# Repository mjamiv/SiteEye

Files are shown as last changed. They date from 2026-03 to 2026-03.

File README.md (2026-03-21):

# SiteEye v0.2

*AI-powered wearable for construction sites. Voice + vision in a badge-sized form factor.*

---

## What Is It

A wearable AI device built on a Raspberry Pi Zero 2W with camera, mic, speaker, and OLED display. Press a button to talk, press another to snap a photo. It sees what you see and talks back.

Designed for construction jobsites — hands-free AI that clips to your vest.

---

## Hardware

### Core
| Part | Model | Notes |
|---|---|---|
| Computer | Raspberry Pi Zero 2W | 64-bit, WiFi, BT |
| Camera | Sony IMX500 AI Camera | On-chip neural net, CSI ribbon |
| Display | Inland 1.3" OLED (SH1106) | SPI mode, IIC/SPI jumper board |
| Microphone | INMP441 I2S MEMS | Digital mic, low output (needs +25dB gain) |
| Amplifier | MAX98357A I2S DAC/Amp | 3W class D, GAIN→GND for 24dB |
| Speaker | PUI Audio AS04004PO-2-R | 4Ω 3W oval |
| Battery | PiSugar 3 + 1200mAh LiPo | Portable power |
| Buttons | Tactile push buttons (×2) | Voice + Camera triggers |

### Form Factor
- Wearable lanyard, badge-sized (~85×55×15-20mm)
- Camera forward, speaker outward, mic hole top
- OLED for glanceable status (animated eyes)

---

## Pin Map

| Pi Pin | GPIO | Device | Function |
|---|---|---|---|
| 1 | 3.3V | OLED | VCC |
| 2 | 5V | MAX98357A | VIN |
| 6 | GND | OLED | GND |
| 9 | GND | INMP441 | GND + L/R (both to GND) |
| 11 | GPIO 17 | Button 2 | Camera |
| 12 | GPIO 18 | INMP441 + MAX | SCK / BCLK (shared) |
| 13 | GPIO 27 | Button 1 | Voice |
| 14 | GND | MAX98357A | GND |
| 17 | 3.3V | INMP441 | VDD |
| 18 | GPIO 24 | OLED | DC |
| 19 | GPIO 10 | OLED | MOSI |
| 22 | GPIO 25 | OLED | RES |
| 23 | GPIO 11 | OLED | CLK |
| 24 | GPIO 8 | OLED | CS |
| 35 | GPIO 19 | INMP441 + MAX | WS / LRC (shared) |
| 38 | GPIO 20 | INMP441 | SD (data in) |
| 40 | GPIO 21 | MAX98357A | DIN (data out) |

### Reserved (future)
| Pi Pin | GPIO | Purpose |
|---|---|---|
| 8 | GPIO 14 | BLE UART TX (nRF52840) |
| 10 | GPIO 15 | BLE UART RX (nRF52840) |
| 15 | GPIO 22 | BLE RST |
| 16 | GPIO 23 | BLE INT |
| 36 | GPIO 16 | NeoPixel RGB LED |

---

## OLED Eyes

SiteEye has expressive Cozmo-style animated eyes powered by `oled_ui.py`:

### Eye Style
- **Filled white rounded rectangles** with black pupil circles and white highlight reflections
- **Lid masking** — black rectangles slide over from top/bottom for expressions
- **Asymmetric scaling** — eyes resize based on look direction (3D perspective effect)

### Expressions
| Expression | Description |
|---|---|
| Idle | Blinks, random look-around, micro-expressions (happy, curious, suspicious, confused) |
| Listening | Wide open, raised eyebrows, pulsing dots |
| Thinking | Squinted, furrowed brows, darting figure-8 eye movement |
| Speaking | Relaxed, gentle sway, mood shifts |
| Happy | Curved bottom lids (smile shape) |
| Angry | Angled top lids, furrowed brows |
| Sad | Droopy brows, angled bottom lids |
| Confused | One brow raised, one flat |
| Suspicious | One eye more squinted than the other |
| Alert | Flash-wide with exclamation mark |
| Sleepy | Slow droop to half-closed |
| Wink | Right eye only |

### Animation Features
- **Boot sequence** — eyes open from closed with quick look-around
- **Smooth pupil tracking** — lerp interpolation for natural movement
- **Saccade movements** — 30% of look changes are fast snaps (like real eyes)
- **Double blink** — 20% chance for natural feel
- **Eased transitions** — smooth in/out on all state changes
- **Eyebrows** — raised (surprise), furrowed (focus), angled (angry/sad)

---

## Software Stack

### OS
- Raspberry Pi OS Lite (64-bit, Bookworm)

### /boot/firmware/config.txt additions
```
dtparam=spi=on
dtparam=i2s=on
dtoverlay=googlevoicehat-soundcard
```

### Dependencies
```bash
sudo apt install -y python3-pip python3-pil python3-spidev sox libsox-fmt-all
pip3 install luma.oled gpiozero
```

### Audio Config

**~/.asoundrc** (and /etc/asound.conf):
```
pcm.speaker {
    type dmix
    ipc_key 1024
    slave {
        pcm "hw:1,0"
        rate 48000
        channels 2
        format S32_LE
    }
}
```

**Amp keepalive service** (eliminates click on play):
```ini
# /etc/systemd/system/amp-keepalive.service
[Unit]
Description=Keep I2S amp alive (no click)
After=sound.target
[Service]
ExecStart=/etc/systemd/system/amp-keepalive.sh
Restart=always
[Install]
WantedBy=multi-user.target
```

---

## Setup

### Quick Start
```bash
git clone https://github.com/mjamiv/SiteEye.git
cd SiteEye
scp main.py oled_ui.py setup-service.sh pi-molt@molt-device.local:~/
ssh pi-molt@molt-device.local "bash setup-service.sh"
```

### Auto-Start Service
The `setup-service.sh` script creates a systemd service that:
- Extracts API keys from `.bashrc` into `~/.env`
- Creates and enables `siteeye.service`
- Starts `main.py` automatically on boot
- Restarts on failure with 5-second delay

### Manual Control
```bash
sudo systemctl status siteeye    # check status
sudo systemctl restart siteeye   # restart
sudo systemctl stop siteeye      # stop
sudo journalctl -u siteeye -f    # live logs
```

---

## Architecture

```
┌─────────────┐     ┌──────────────┐     ┌──────────────┐
│   SiteEye   │────▶│  VPS Proxy   │────▶│  AI Backend  │
│  (Pi Zero)  │◀────│  :5757       │◀────│              │
└─────────────┘     └──────────────┘     └──────────────┘
      │                    │
      │                    ├──▶ Whisper (STT)
      ├──▶ TTS Engine      ├──▶ GPT-4o (Vision)
      ├──▶ Telegram Bot     └──▶ Sonnet (Chat)
      └──▶ OLED Display
```

### Voice Flow
1. Press Voice button → eyes go wide ("listening")
2. Record I2S mic (S32_LE, 48kHz, stereo)
3. Press again → stop recording
4. Sox boost +25dB, convert to 16kHz mono → Whisper STT
5. Eyes squint ("thinking") → Proxy `/chat` → AI response
6. Response on OLED → TTS → sox EQ → speaker
7. Eyes return to idle animation

### Camera Flow
1. Press Camera button → eyes flash alert ("capturing")
2. rpicam-still 640×480 with vflip/hflip
3. Photo sent to Telegram via bot API
4. Eyes squint ("thinking") → Proxy `/vision` → GPT-4o analysis
5. Response on OLED → TTS → speaker
6. Eyes return to idle

### Audio EQ
```
bass +6 | treble -7 3000 | lowpass 8000
```
De-esses sibilance, adds warmth. Tuned for small speaker output.

---

## Key Files

| File | Purpose |
|---|---|
| `main.py` | Device client — voice/camera flows, button handling |
| `oled_ui.py` | OLED animated eyes engine (Cozmo-style) |
| `server.py` | VPS proxy server |
| `setup-service.sh` | Auto-start service installer |

---

---

## Case Design — 3D Printed Wearable Enclosure

SiteEye ships in a custom-designed 3D printed badge-sized enclosure. Full design docs, OpenSCAD source, and STL exports are in [`case-design/`](case-design/).

### v6 Enclosure (Current)

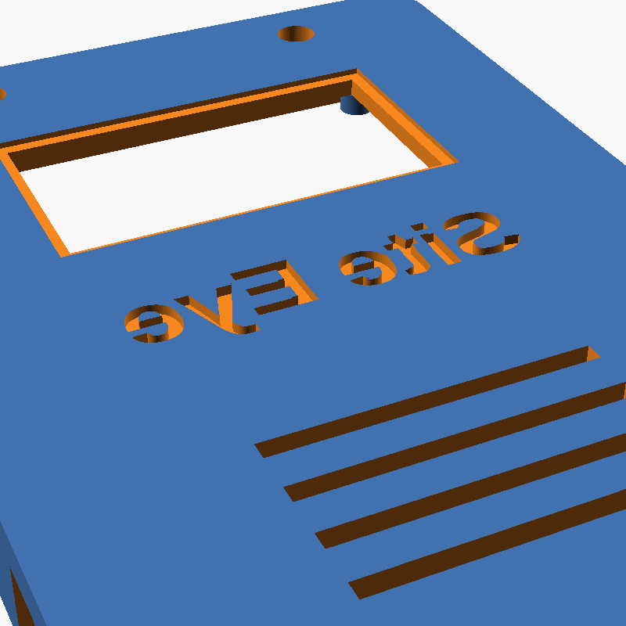
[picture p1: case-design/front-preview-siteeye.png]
SiteEye Front Shell Preview


**Form factor:** 58 × 82 × 34mm — badge-sized, lanyard-worn at chest level.

- **Two-piece snap-fit** — front shell (camera side) + back shell (OLED side), clip together at 4 corners
- **Camera faces forward** — IMX500 on the front shell, sees what you see
- **OLED faces you** — 1.3" display on the back shell, readable by glancing down
- **Single inset lanyard loop** at top — breakaway clasp for construction site safety
- **Integrated component cradles** — 36mm speaker cradle, 14mm mic cradle, Pi Zero 2W standoff pattern
- **PETG (black)** — heat/impact resistant, professional look, ~22g filament per enclosure

The v6 design addresses 13 issues from prototype review: corrected OLED mounts, dedicated mic vent, speaker cradle, bottom USB access, right-reading labels, and full interior clearance for all components including PiSugar battery.

### Build Photos

| Photo | Description |
|---|---|
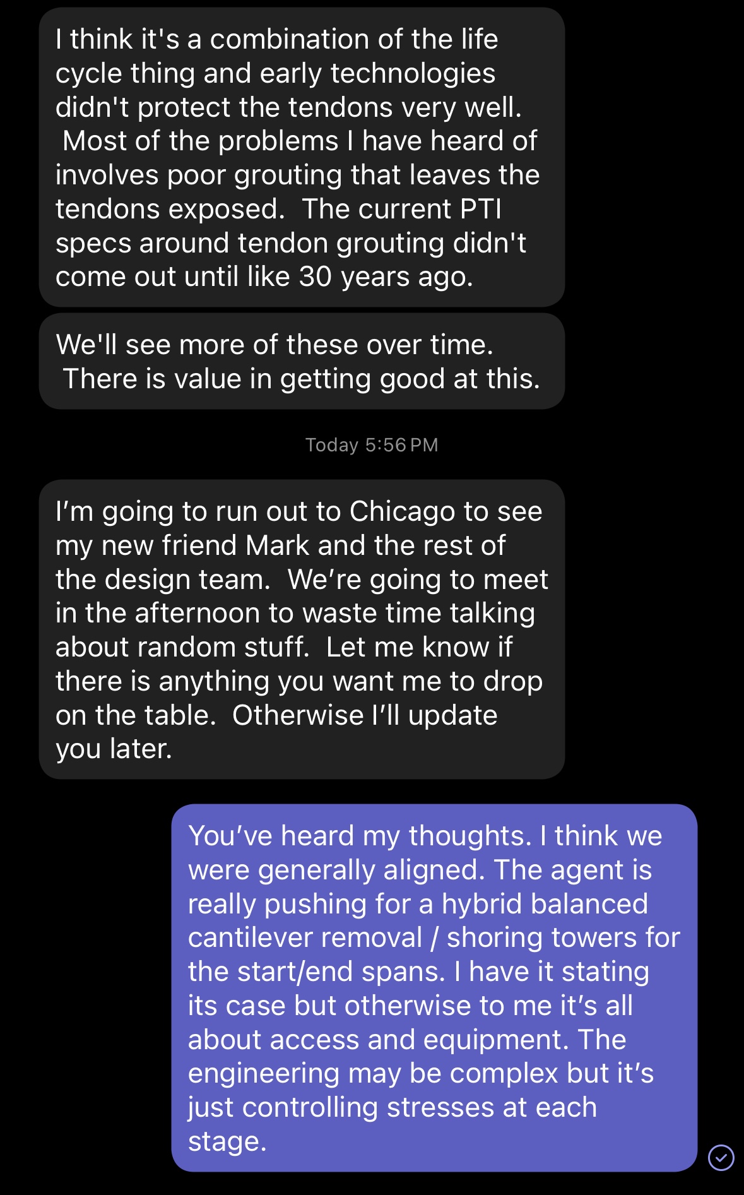
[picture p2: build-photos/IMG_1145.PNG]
|  | Assembly overview |
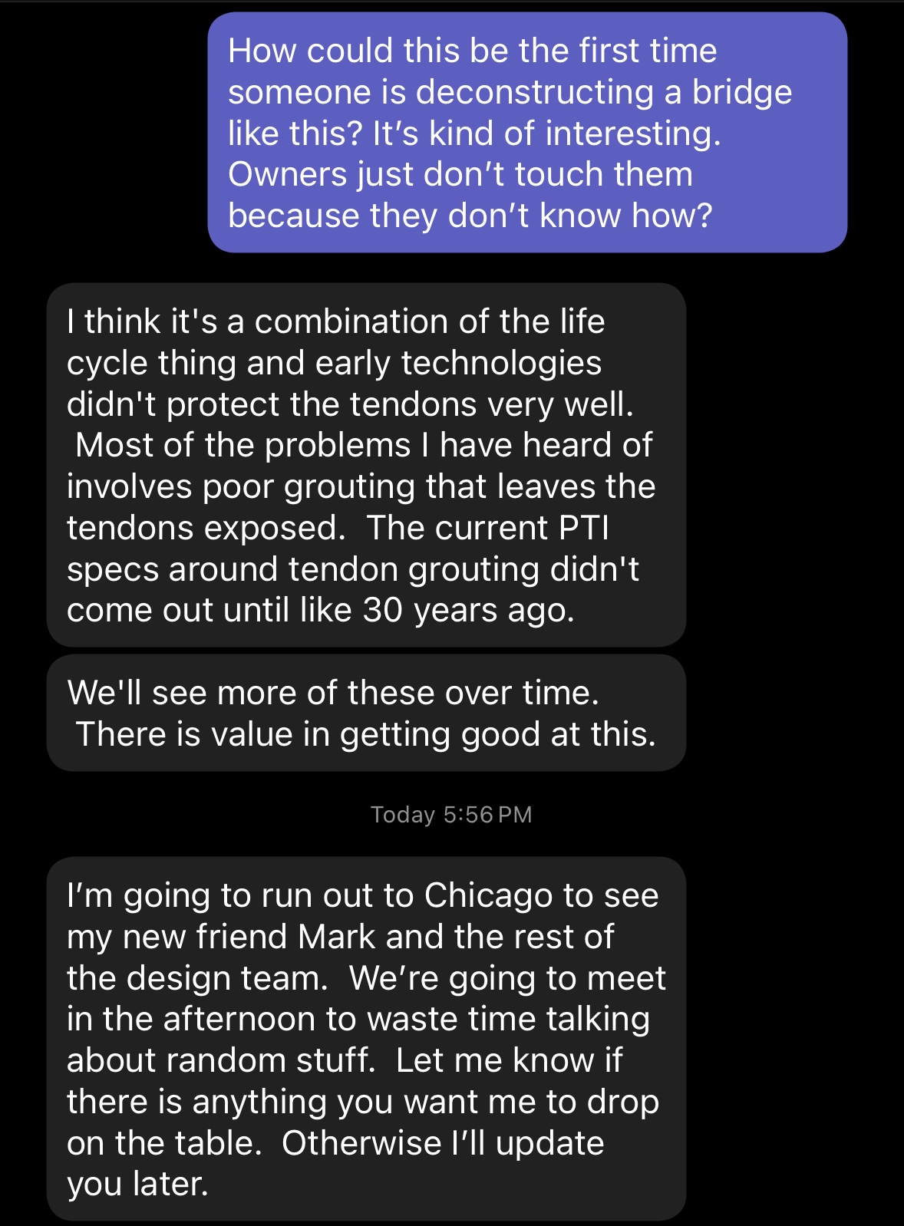
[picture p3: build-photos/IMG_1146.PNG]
|  | Front shell detail |
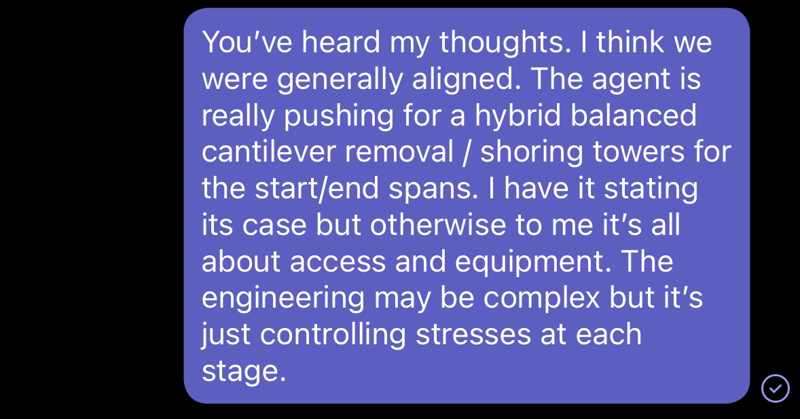
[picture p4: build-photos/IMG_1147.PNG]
|  | Internal components |
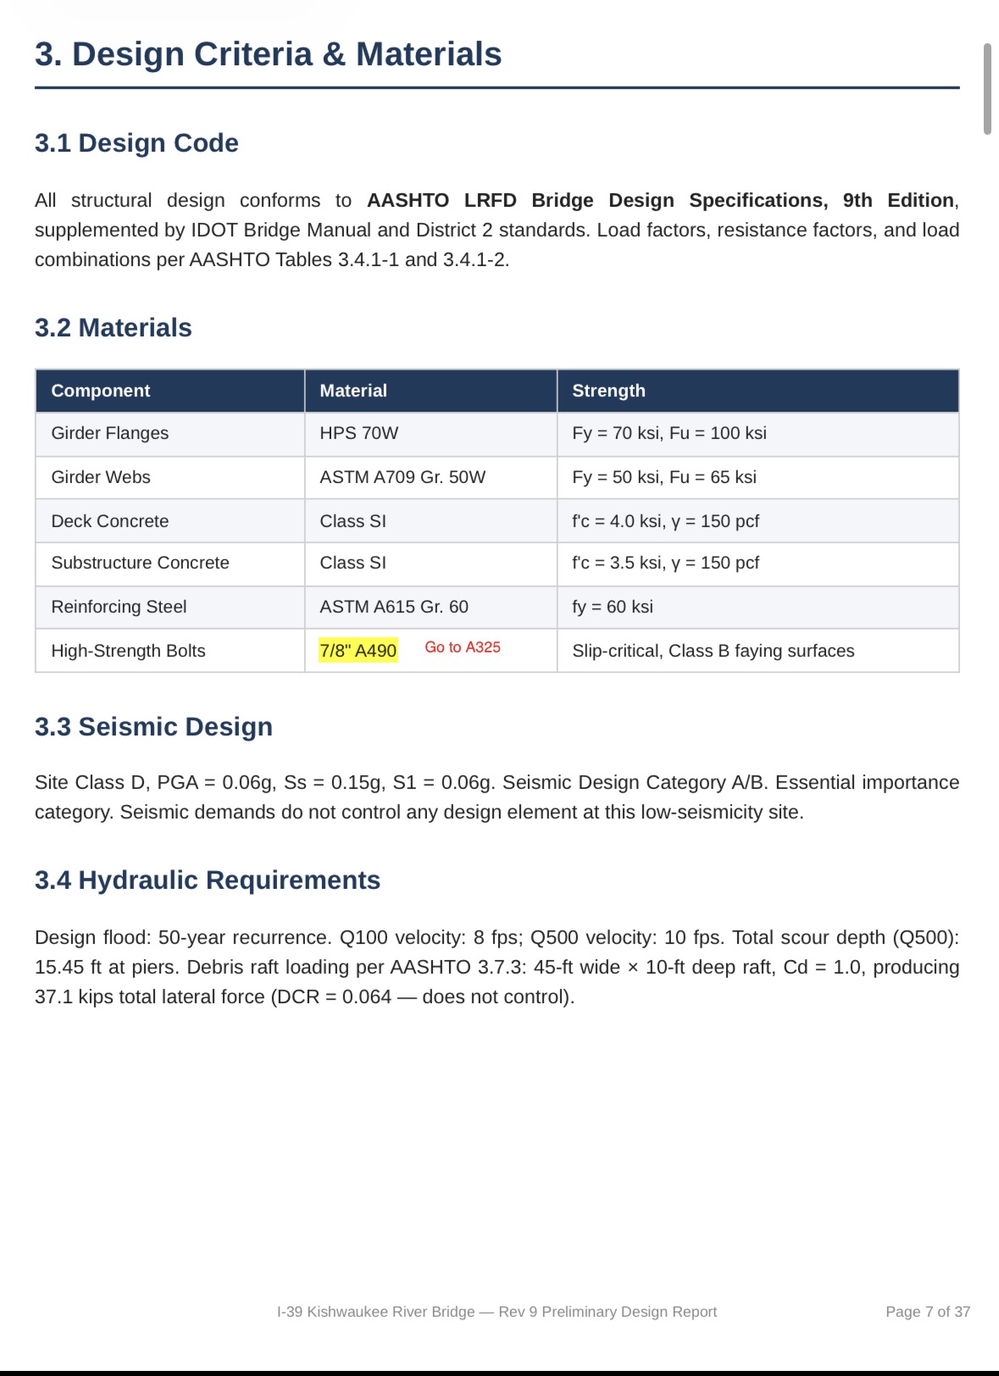
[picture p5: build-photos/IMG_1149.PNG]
|  | Camera mount |
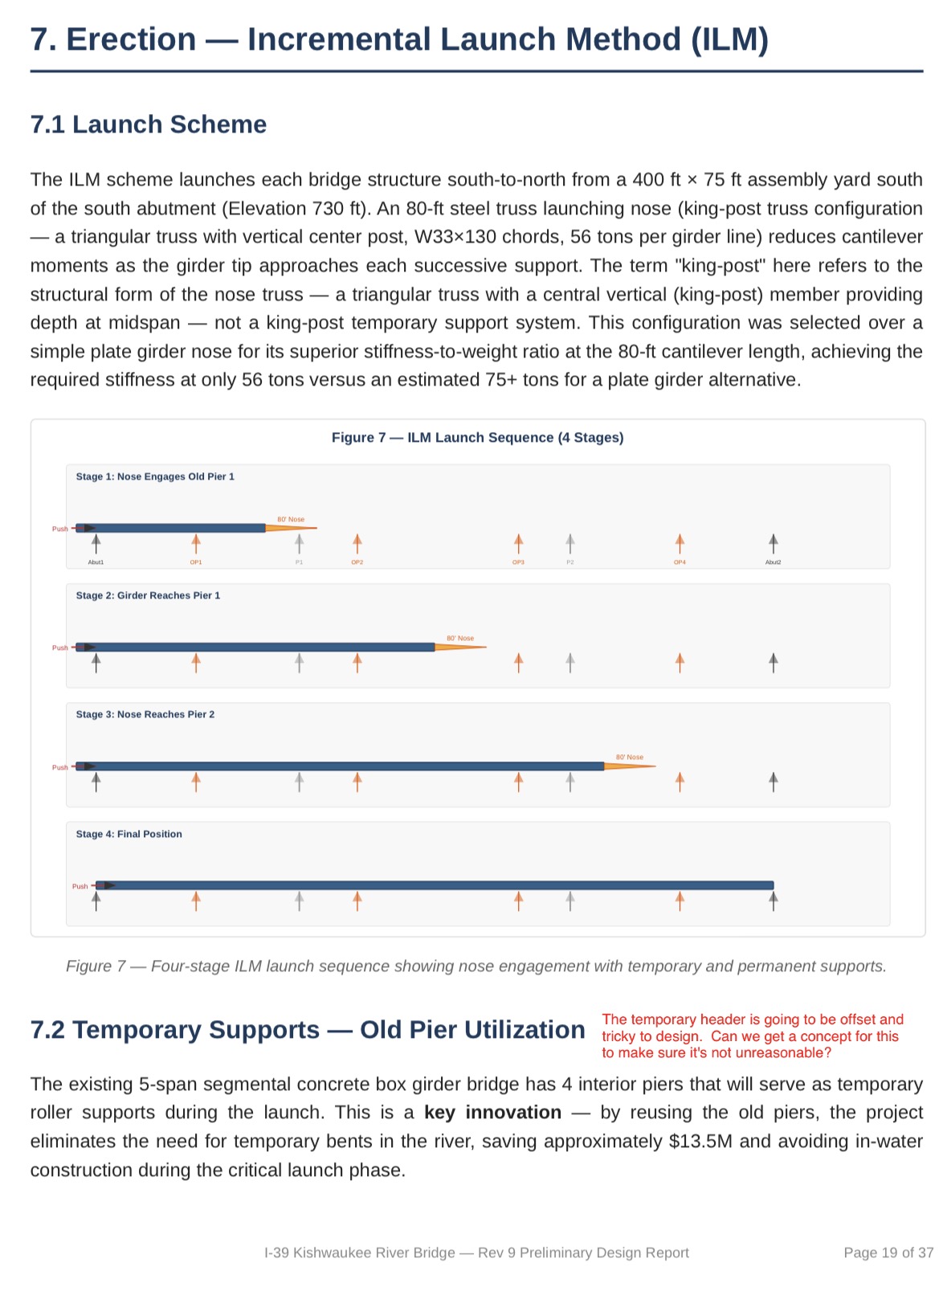
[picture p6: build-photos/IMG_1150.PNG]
|  | OLED side |
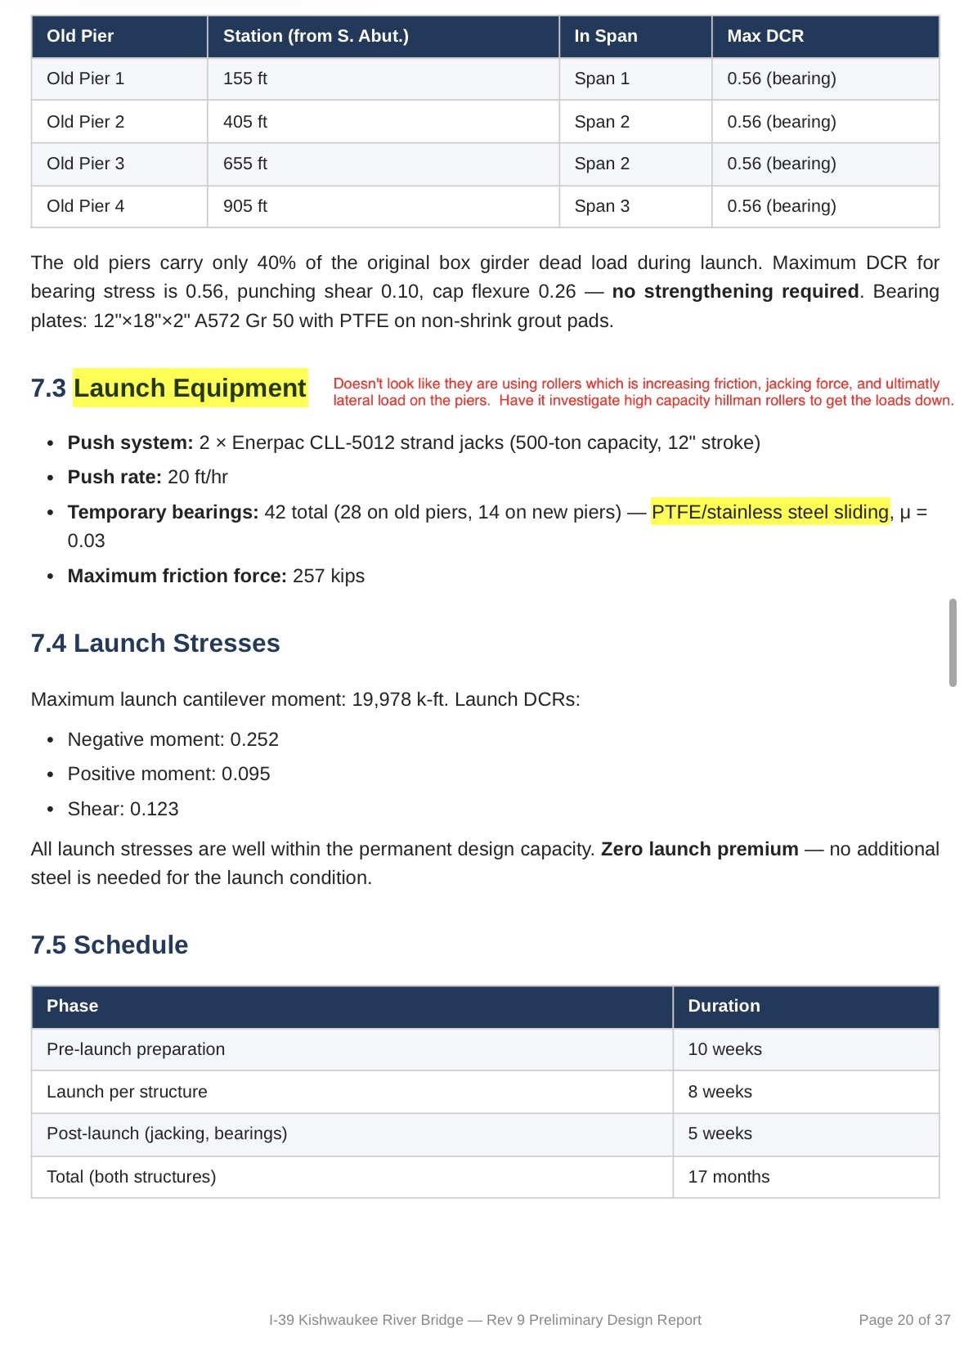
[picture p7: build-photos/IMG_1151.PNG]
|  | Assembled unit |
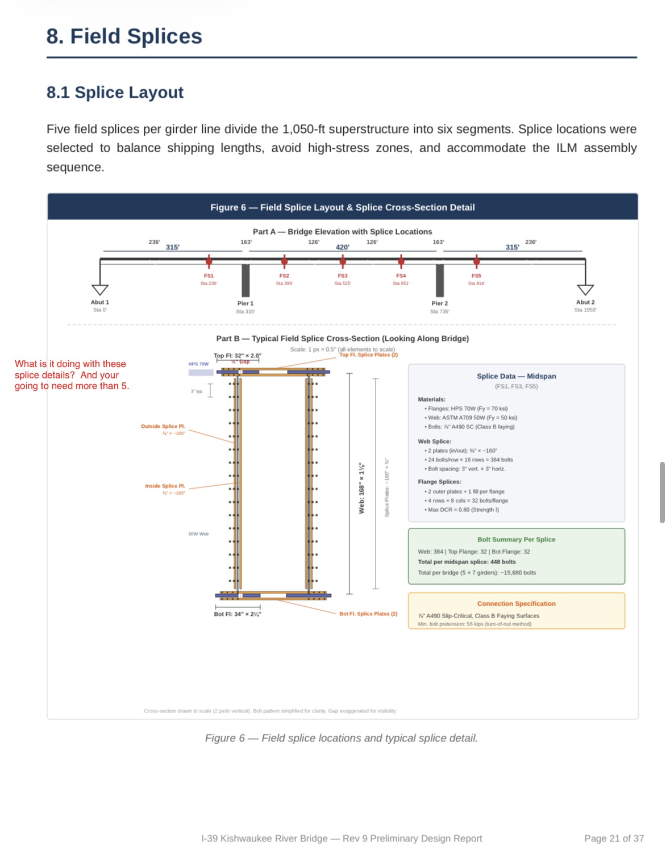
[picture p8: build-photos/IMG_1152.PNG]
|  | Worn on lanyard |
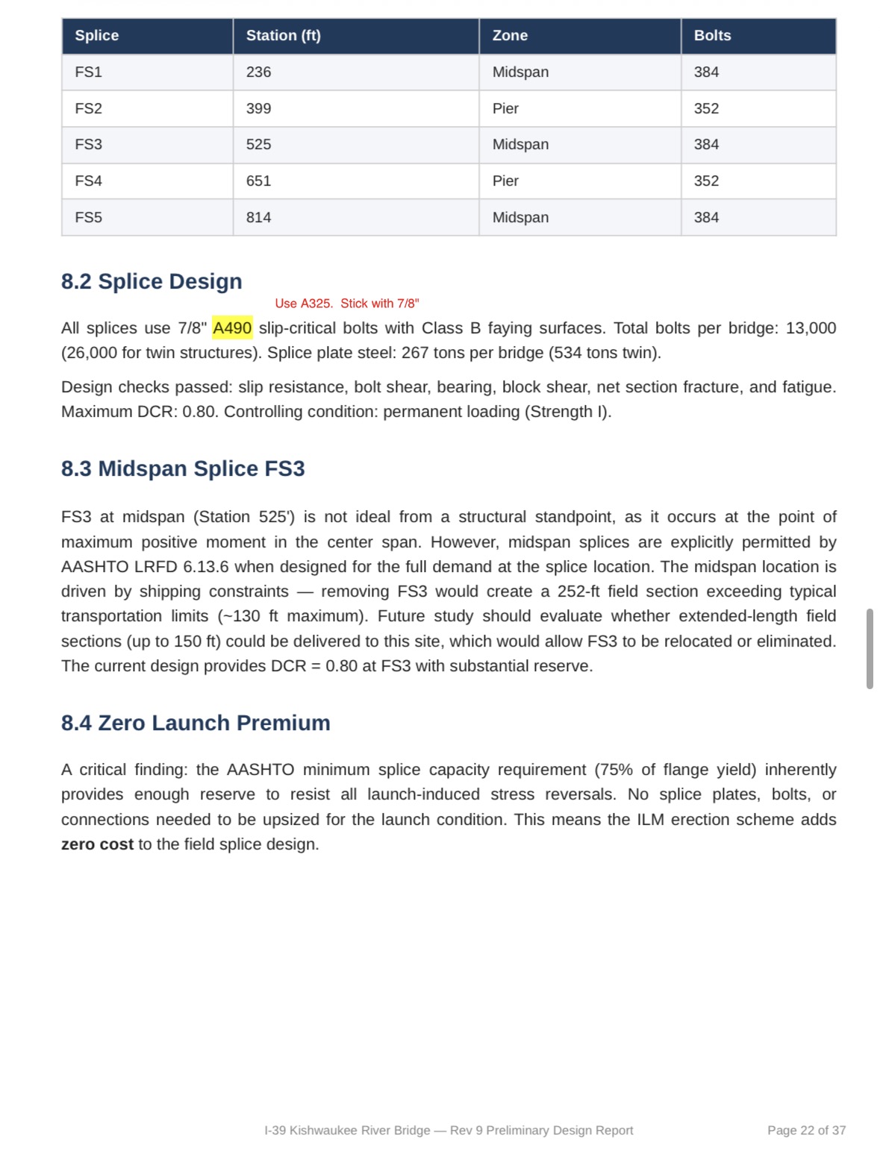
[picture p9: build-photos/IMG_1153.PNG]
|  | Side profile |

→ **[Full case design docs, STL files, and printing instructions](case-design/README.md)**

---

## Hardware Status

| Component | Status |
|---|---|
| Pi Zero 2W | ✅ Working |
| IMX500 AI Camera | ✅ Working |
| 1.3" OLED (SH1106) | ⚠️ Broken (hardware fault) |
| INMP441 Mic + MAX98357A Amp | ✅ Working |
| PUI Audio Speaker | ✅ Working |
| PiSugar 3 + 1200mAh LiPo | ✅ Working |
| Tactile Buttons (×2) | 🔲 Pending wiring |
| 3D Printed Enclosure (v6) | ✅ Designed, printing |
| NeoPixel RGB LED | 🔲 Not purchased |

---

## Known Issues & TODO
- [ ] OLED broken — replacement needed
- [ ] NeoPixel LED not purchased/wired
- [ ] Buttons pending wiring to GPIO 17/27
- [ ] OLED sometimes needs `sudo killall python3` before restart (GPIO not released)
- [ ] BLE 5.0 mesh networking (nRF52840 DNP on PCB for v1)

---

## Lessons Learned
1. **SPI speed matters on breadboard.** Default 8MHz fails — 500kHz works reliably with jumper wires.
2. **Process exit resets OLED.** luma.oled cleans up GPIO on exit — display goes blank. Keep process alive.
3. **INMP441 records low.** Always boost +20-25dB with sox before sending to STT.
4. **I2S format must match exactly.** 48kHz stereo S32_LE for both record and playback.
5. **Breadboard rows can be unreliable.** DIN wire worked direct but not through breadboard.
6. **Amp keepalive eliminates click.** dmix + silent background stream prevents power cycle pop.
7. **Buttons wire across, not along.** Same-side legs are always connected — wire to opposite legs.
8. **Kill all python3 before restarting.** GPIO won't allocate if previous process still holds pins.
9. **De-ess small speakers.** treble -7 @3kHz + lowpass 8kHz tames sibilance without killing clarity.
10. **Filled rounded rects > outlined ellipses.** Way more contrast and readability on tiny OLEDs. The Cozmo/Vector style works.
11. **Saccades make eyes feel alive.** Mix fast snaps with smooth tracking — real eyes do both.

---

## License

MIT

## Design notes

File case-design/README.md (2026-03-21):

# SiteEye Case Design — 3D Printed Wearable Enclosure

**v6 design** — Full redesign per 13-point review, March 17, 2026

---

## Form Factor

**Badge-sized wearable lanyard** — think of it as a smarter ID badge.

| Dimension | Value |
|---|---|
| Width | 58mm |
| Height | 82mm |
| Assembled Depth | 34mm (front shell 16mm + back shell 18mm) |
| Corner Radius | 4mm fillets |
| Wall Thickness | 2mm |
| Estimated Weight | ~85g assembled |

Portrait orientation, worn on a lanyard at chest level. Camera faces forward (toward what you're looking at). OLED faces you (readable by glancing down). Matches the badge convention — at home on a construction jobsite.

---

## Two-Piece Snap-Fit Design

The enclosure splits into **front shell** and **back shell**, joined by snap-fit clips at all four corners. Optional M2 screws for ruggedized/job-site use.

```
FRONT SHELL (camera side)           BACK SHELL (OLED side)
┌─────────────────────┐             ┌─────────────────────┐
│  ○  lanyard loop    │             │  ○  lanyard loop    │
│                     │             │                     │
│   ░░░░░ speaker     │             │  ┌───────────────┐  │
│   ░░░░░ vents       │             │  │  1.3" OLED    │  │
│                     │             │  │  128 × 64     │  │
│    ┌───┐  camera    │             │  └───────────────┘  │
│    │ ◉ │  lens      │             │                     │
│    └───┘            │             │  [BTN1]    [BTN2]   │
│                     │             │                     │
│  "Site Eye"         │             │                     │
│  "Prototype v1"     │             │                     │
│                     │             │                     │
│   ◎  mic vent       │             │                     │
│                     │             │                     │
└────────┬────────────┘             └─────────────────────┘
         │
    micro-USB (bottom)
```

**Print orientation:** Each shell face-down (outer face on build plate). Best surface finish on the visible face, snap-fit clips print vertically for maximum strength.

---

## Component Mounting

| Component | Location | Mounting Method |
|---|---|---|
| Pi Zero 2W | Back shell interior | M2.5 standoffs, 23×58mm c-c pattern |
| IMX500 AI Camera | Front shell (forward-facing) | Camera cradle, 8mm lens opening with bezel |
| 1.3" OLED (SH1106) | Back shell (user-facing) | 4-post mount, 30mm c-c, 3mm screw holes |
| Speaker (4Ω 3W oval) | Front shell | 36mm speaker cradle behind vent slots |
| MEMS Microphone (INMP441) | Front shell top | 14mm mic cradle behind vent hole |
| PiSugar 3 LiPo battery | Back shell, between Pi and back wall | Snap-in, accessible from bottom |
| Tactile buttons (×2) | Back shell, below OLED | Cutouts for right-thumb access |

**CSI ribbon cable** routes through internal channel from camera (front) to Pi (back), with 180° fold.

---

## v6 Design — 13-Point Redesign

Version 6 is a full redesign addressing 13 issues from prototype review (March 17, 2026):

1. **Labels mirrored** — correct exterior reading (right-reading when printed face-down)
2. **Labels on camera (front) side** — smaller font, cleaner look
3. **Camera moved down ~19mm** — better FOV from chest-level position
4. **OLED mounts corrected** — 30mm c-c, 3mm holes, 35.5×33.5mm module, 34×18.5mm screen window
5. **Assembled depth 34mm** — 16mm front + 18mm back = 30mm+ internal clearance for all components
6. **Front mic opening added** — dedicated vent hole for INMP441 microphone
7. **Side micro-USB slot** — 10mm deep × 20mm wide, 15mm from top, for power access
8. **Bottom opening** — single centered hole for micro-USB access (cleaner than per-shell holes)
9. **36mm speaker cradle** — behind front vent slots, sized for PUI Audio AS04004PO-2-R
10. **14mm mic cradle** — behind front mic opening, holds INMP441 in position
11. **Single inset lanyard loop** — at top center (replaces dual lanyard holes, stronger)
12. **Pi Zero 2W screw holes** — 23×58mm c-c, centered on back plate
13. **Tactile button cutouts** — on back shell below OLED (replaced removed back vents)

---

## Files

### OpenSCAD Source
| File | Description |
|---|---|
| `molt-case.scad` | Main parametric model (v6, all components) |
| `export-front.scad` | Front shell export (with text labels) |
| `export-front-notext.scad` | Front shell export (no text, cleaner) |
| `export-back.scad` | Back shell export |
| `render-preview.scad` | Assembled preview render |

### STL Exports
| File | Description |
|---|---|
| `molt-case-front-v6.stl` | **Current** — front shell with labels |
| `molt-case-front-v6-notext.stl` | **Current** — front shell, no text |
| `molt-case-back-v6.stl` | **Current** — back shell |
| `molt-case-front-v5.stl` | v5 front (reference) |
| `molt-case-front-v4-siteeye.stl` | v4 front with SiteEye branding |
| `molt-case-back-v4.stl` | v4 back (reference) |

### Visualization
| File | Description |
|---|---|
| `front-preview-siteeye.png` | Rendered preview of front shell |

---

## Printing Instructions

### Recommended Settings

| Parameter | Value |
|---|---|
| **Material** | PETG (black) — preferred for heat/impact resistance |
| **Alternative** | PLA — faster iteration during development |
| **Layer Height** | 0.2mm |
| **Wall Perimeters** | 3 (strength for snap-fits) |
| **Infill** | 15-20% gyroid or honeycomb |
| **Print Temperature** | 230°C (PETG) / 215°C (PLA) |
| **Bed Temperature** | 70°C (PETG) / 60°C (PLA) |
| **Supports** | Minimal — button cutouts may need minimal support |
| **Orientation** | Face-down on bed (outer surface = best finish) |

### Time & Material
- Front shell: ~2.5 hrs, ~12g
- Back shell: ~2 hrs, ~10g
- Total filament: ~22g per enclosure (~$1.10 in PETG)

---

## Assembly Guide

### Tools Needed
- M2.5 × 6mm standoffs (4×)
- M2.5 × 4mm screws (8×)
- M2 × 6mm screws (2×, optional — for snap-fit reinforcement)
- Tweezers for ribbon cable routing
- Thin double-sided tape for wire management

### Step-by-Step

1. **Install Pi standoffs** — Thread 4× M2.5 standoffs into back shell mounting holes (23×58mm pattern, centered)

2. **Mount Pi Zero 2W** — Seat on standoffs, screw with M2.5 × 4mm screws. Leave GPIO header accessible.

3. **Route CSI ribbon** — Thread camera ribbon cable through the internal channel. Leave slack for 180° fold.

4. **Install OLED** — Seat into 4-post mount on back shell. Ribbon or wire down to Pi GPIO (SPI: pins 8, 10, 11, 24, 25).

5. **Install buttons** — Press tactile switches into button cutouts on back shell. Wire to Pi GPIO 17 (camera) and GPIO 27 (voice).

6. **Install microphone** — Seat INMP441 into 14mm mic cradle behind front shell mic vent. Route wires through interior.

7. **Install speaker** — Seat speaker into 36mm front-shell cradle behind vent slots. Connect to MAX98357A amp.

8. **Attach PiSugar battery** — Connect to Pi Zero 2W (attaches underneath Pi). Add last — interferes with debugging.

9. **Connect camera** — Attach IMX500 AI Camera to Pi CSI port via ribbon. Seat camera in front-shell lens pocket.

10. **Snap shells together** — Align front and back shell, press at all four corners until clips engage.

11. **Thread lanyard** — Route through top inset loop, attach breakaway clasp.

> ⚠️ **Add PiSugar last.** The battery module physically blocks GPIO access once installed.

---

## Version History

| Version | Date | Key Changes |
|---|---|---|
| v1/v2 | Feb 2026 | Initial concept — badge form factor proof |
| v3 | Mar 2026 | First printable model |
| v4 | Mar 2026 | SiteEye branding, camera bezel |
| v5 | Mar 2026 | OLED mount fixes, button placement |
| **v6** | **Mar 17, 2026** | **13-point redesign — current version** |

---

## Design Rationale

| Decision | Choice | Why |
|---|---|-----|
| Orientation | Portrait (vertical) | Matches badge convention, natural chest hang |
| Camera side | Front shell (forward-facing) | Captures user's perspective |
| OLED side | Back shell (user-facing) | Readable by glancing down |
| Buttons | Back shell, below OLED | Right-thumb access while hanging |
| Assembly | Snap-fit + optional screws | Fast iteration + job-site durability |
| Material | PETG (black) | Heat/impact resistant, professional look |
| Cooling | Passive vents only | Pi Zero 2W thermals manageable without fan |
| Lanyard | Single loop (breakaway) | Safety-critical for construction sites |
| Depth | 34mm assembled | Accommodates all components including PiSugar |
| Labels | Camera (front) side only | Clean OLED side, branded front |

---

*Designed by Molt AI for Michael Martello. Living document — updates with each revision.*

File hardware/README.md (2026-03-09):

# SiteEye Hardware — PCB Design

## Overview

Custom PCB to replace breadboard wiring. Eliminates signal integrity issues (SPI speed, I2S timing) and fits the badge-sized wearable form factor.

## Design Goals

1. **Badge form factor:** ~85×55mm, 2-layer PCB
2. **Pi Zero 2W** mounts via 2×20 GPIO header (removable) or castellated pads (permanent)
3. **All peripherals on-board:** OLED, mic, amp, buttons, speaker connector
4. **BLE 5.0 mesh-ready:** Unpopulated footprint for nRF52840 or ESP32-C3 module (future multi-device mesh networking for jobsites without cell service)
5. **PiSugar compatible:** Clearance underneath for PiSugar 3 battery board
6. **Camera:** CSI ribbon passthrough (not on PCB)

## Components

| Ref | Component | Package | Notes |
|-----|---|---|---|
| U1 | Raspberry Pi Zero 2W | 2×20 header | Host computer |
| U2 | INMP441 | Breakout board | I2S MEMS microphone |
| U3 | MAX98357A | Breakout board | I2S DAC/amplifier |
| U4 | SH1106 1.3" OLED | SPI breakout | Display |
| U5 | nRF52840 module | Castellated (future) | BLE 5.0 mesh radio — DNP v1 |
| SW1 | Tactile button | 6mm 4-pin | Voice trigger |
| SW2 | Tactile button | 6mm 4-pin | Camera trigger |
| LED1 | NeoPixel WS2812B | 5050 SMD | Status RGB LED |
| SP1 | PUI AS04004PO-2-R | Wire pads | 4Ω 3W speaker |
| J1 | CSI ribbon connector | 22-pin FPC | Camera passthrough |
| J2 | JST-PH 2-pin | Through-hole | Speaker connector |
| J3 | 2×20 GPIO header | 2.54mm pitch | Pi Zero mount |

## Net List

### Power Rails
| Net | Source | Destinations |
|-----|---|---|
| 3V3 | Pi Pin 1 | OLED VCC, INMP441 VDD |
| 5V | Pi Pin 2 | MAX98357A VIN |
| GND | Pi Pin 6,9,14 | All components |

### I2S Audio Bus (shared)
| Net | Pi GPIO | Pin | Destinations |
|-----|---|-----|---|
| I2S_BCLK | GPIO 18 | 12 | INMP441 SCK, MAX98357A BCLK |
| I2S_LRCLK | GPIO 19 | 35 | INMP441 WS, MAX98357A LRC |
| I2S_DIN | GPIO 20 | 38 | INMP441 SD (mic data) |
| I2S_DOUT | GPIO 21 | 40 | MAX98357A DIN (speaker data) |

### SPI Display
| Net | Pi GPIO | Pin | Destination |
|-----|---|-----|---|
| SPI_MOSI | GPIO 10 | 19 | OLED MOSI |
| SPI_CLK | GPIO 11 | 23 | OLED CLK |
| SPI_CS | GPIO 8 | 24 | OLED CS |
| OLED_DC | GPIO 24 | 18 | OLED DC |
| OLED_RST | GPIO 25 | 22 | OLED RES |

### GPIO
| Net | Pi GPIO | Pin | Destination |
|-----|---|-----|---|
| BTN_VOICE | GPIO 27 | 13 | SW1 (pull-up, active low) |
| BTN_CAMERA | GPIO 17 | 11 | SW2 (pull-up, active low) |
| NEOPIXEL | GPIO 16 | 36 | LED1 data in |

### INMP441 Config
| Pin | Connection |
|-----|---|
| L/R | GND (left channel select) |

### MAX98357A Config
| Pin | Connection |
|-----|---|
| GAIN | GND (24dB fixed gain) |
| SD | NC or pull-up (always on) |

### BLE Mesh Module (future, v2+)
| Net | Pi GPIO | Module Pin | Notes |
|-----|---|---|---|
| UART_TX | GPIO 14 | RXD | Serial command interface |
| UART_RX | GPIO 15 | TXD | Serial command interface |
| BLE_RST | GPIO 22 | RESET | Module reset |
| BLE_INT | GPIO 23 | IRQ | Interrupt line |
| 3V3 | — | VCC | Shared 3.3V rail |
| GND | — | GND | — |

## PCB Layout Notes

### Layer Stack
- **Top:** Components, signal traces
- **Bottom:** Ground plane, PiSugar clearance

### Placement
```
┌──────────────────────────────┐
│  [OLED]          [CAM ribbon]│
│                              │
│  [MIC]    [nRF52840 future]  │
│                              │
│  [SW1]  [SW2]  [NeoPixel]   │
│                              │
│  ════════════════════════════│ ← Pi Zero GPIO header
│  [MAX98357A]    [Speaker J2] │
└──────────────────────────────┘
        (bottom: PiSugar)
```

### Design Rules
- Trace width: 0.25mm signal, 0.5mm power
- Clearance: 0.2mm minimum
- Via size: 0.3mm drill, 0.6mm pad
- I2S traces: matched length, keep short
- SPI traces: keep under 50mm, ground guard
- Decoupling caps: 100nF on each VCC pin

## BOM (v1 — no mesh radio)

| Qty | Part | Est. Cost |
|-----|---|---|
| 1 | Custom PCB (5 pcs) | $5-15 |
| 1 | 2×20 female header | $1 |
| 2 | 6mm tactile button | $0.50 |
| 1 | WS2812B NeoPixel | $0.30 |
| 1 | JST-PH 2-pin connector | $0.20 |
| 4 | 100nF 0805 caps | $0.10 |
| — | **Total per board** | **~$7-17** |

(Breakout boards for INMP441, MAX98357A, OLED, Pi Zero purchased separately)

## Fabrication

Recommended fabs:
- **JLCPCB** — cheapest, 5 boards ~$5, PCBA available
- **PCBWay** — good quality, slightly more
- **OSH Park** — US-based, purple boards, ~$15 for 3

## Future: Bluetooth Mesh (v2+)

The nRF52840 footprint enables BLE 5.0 Mesh networking for multi-device jobsite communication without cell service. Architecture:

```
[SiteEye A] ←BLE Mesh→ [SiteEye B] ←BLE Mesh→ [SiteEye C]
     ↑                       ↑                       ↑
  Worker 1              Worker 2              Worker 3
                             ↓
                    [Gateway Node]
                         ↓
                   [Cloud/Server]
```

- Mesh relay: each device acts as a node, forwarding messages
- Range: ~100m outdoor per hop, multi-hop extends coverage
- Use cases: safety alerts, task coordination, voice relay, location tracking
- Protocol: Bluetooth Mesh (IEEE 802.15.1) or custom on BLE 5.0 advertising

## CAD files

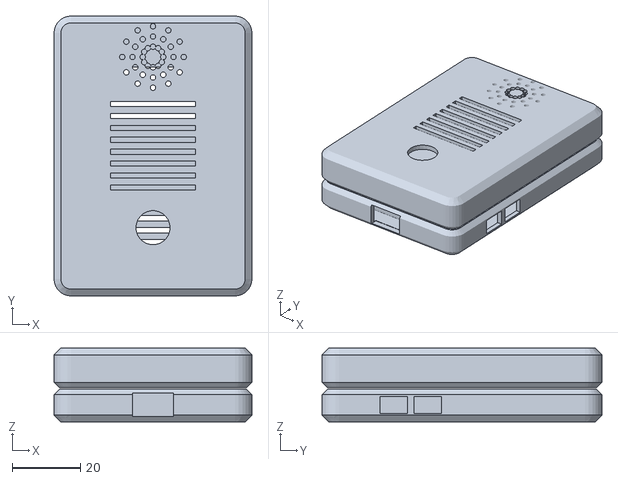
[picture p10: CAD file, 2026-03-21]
case-design/molt-device-assembled.stl
58.0 x 82.0 x 21.6

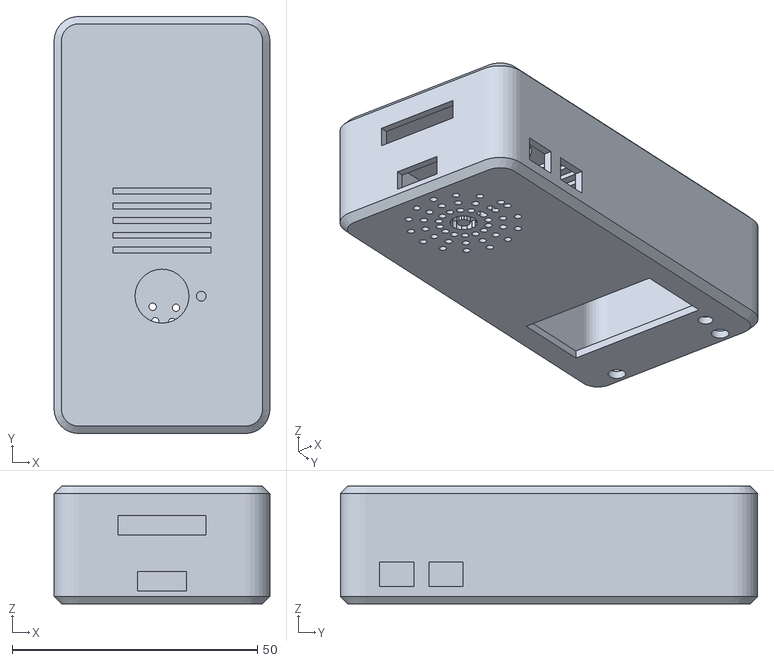
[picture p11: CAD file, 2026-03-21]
case-design/molt-v2-assembled.stl
44.0 x 85.0 x 24.0

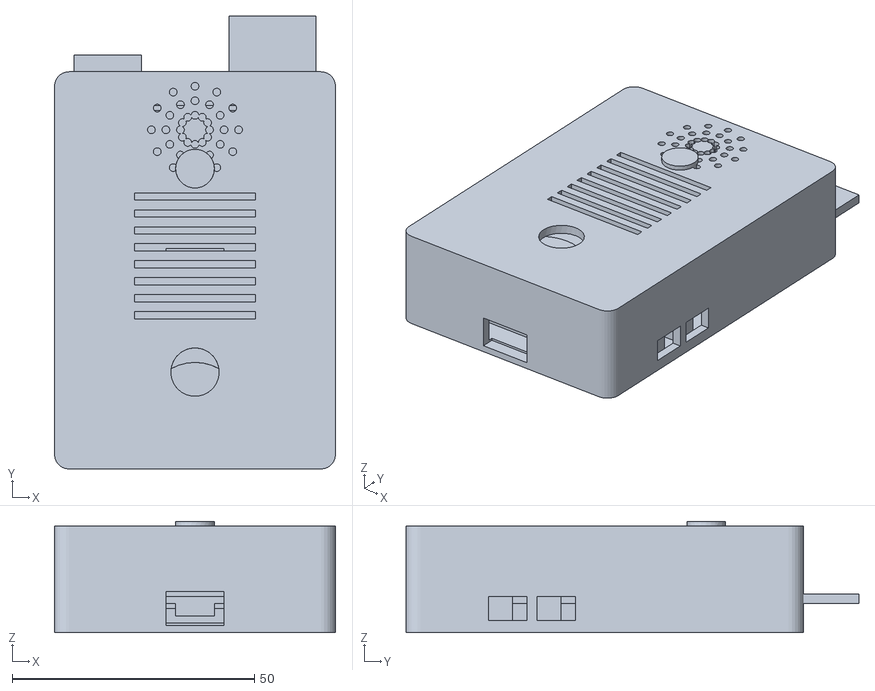
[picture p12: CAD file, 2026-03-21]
case-design/molt-device-full-model.stl
58.0 x 93.5 x 23.0

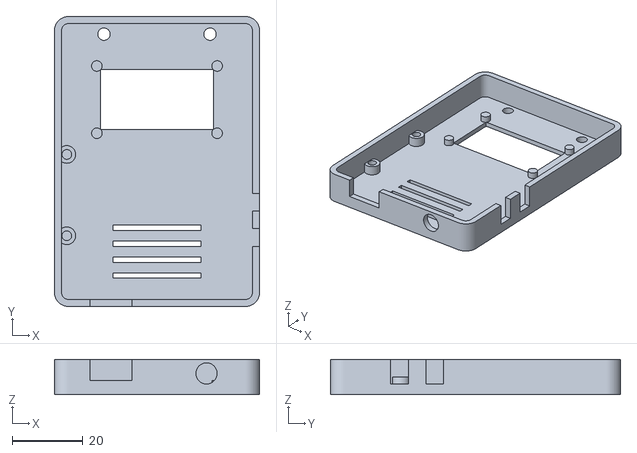
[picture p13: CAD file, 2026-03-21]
case-design/molt-case-front-v4-siteeye.stl
58.0 x 82.0 x 10.0

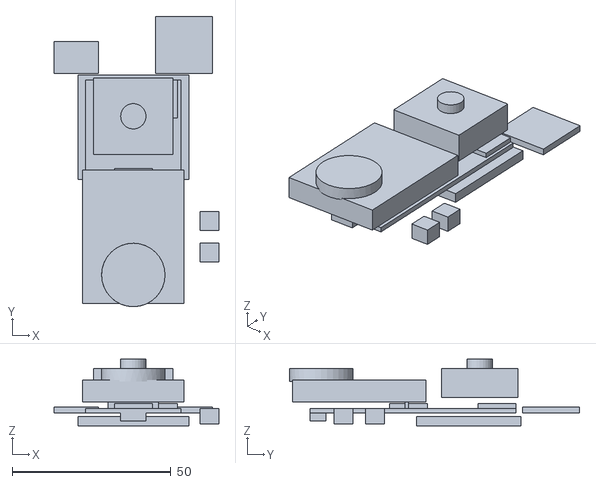
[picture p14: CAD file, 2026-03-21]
case-design/molt-device-components.stl
52.0 x 91.5 x 21.0

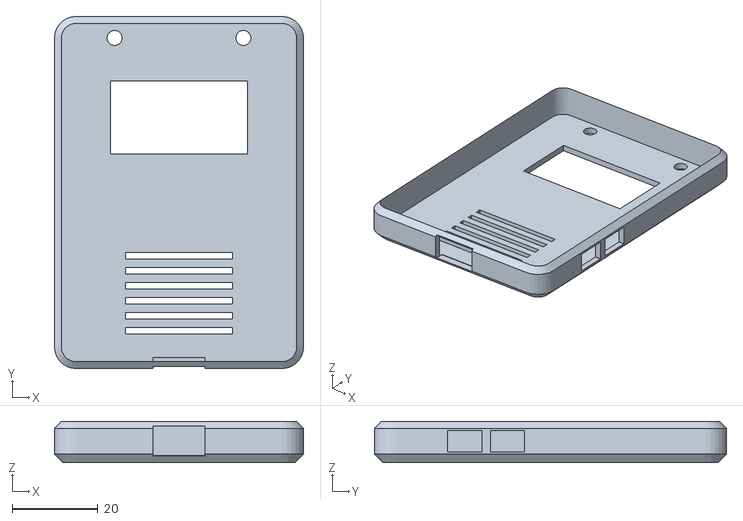
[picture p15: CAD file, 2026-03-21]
case-design/molt-device-front.stl
58.0 x 82.0 x 9.60

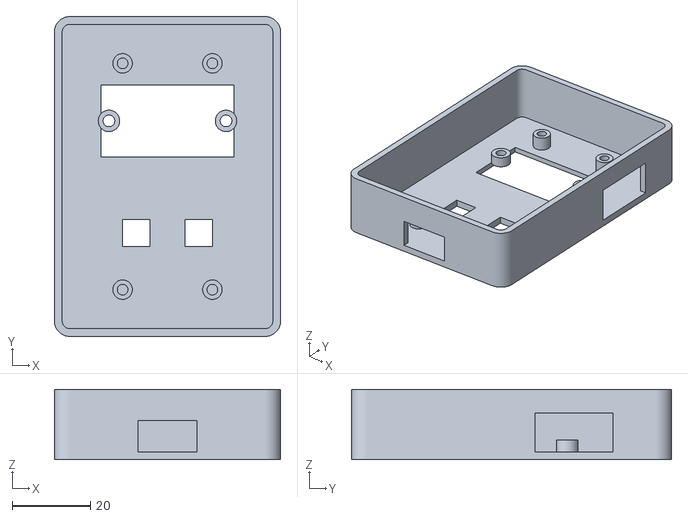
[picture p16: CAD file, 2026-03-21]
case-design/molt-case-back-v6.stl
58.0 x 82.0 x 18.0

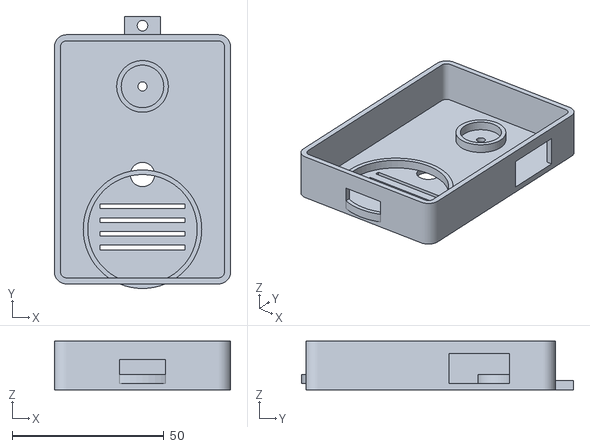
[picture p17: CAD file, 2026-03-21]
case-design/molt-case-front-v6.stl
58.0 x 89.5 x 16.0

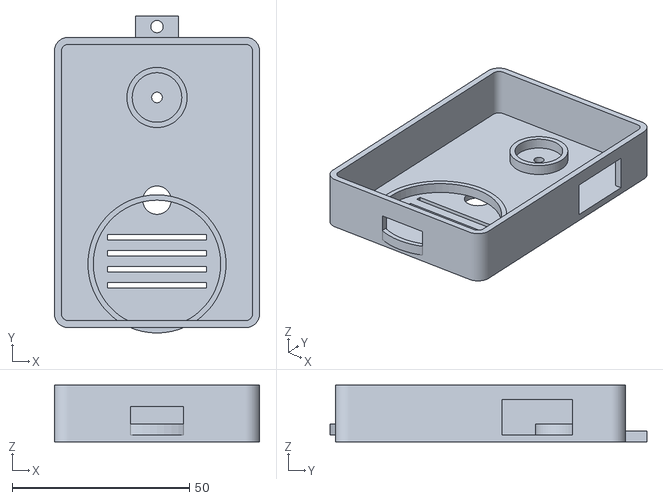
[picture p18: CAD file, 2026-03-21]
case-design/molt-case-front-v6-notext.stl
58.0 x 89.5 x 16.0

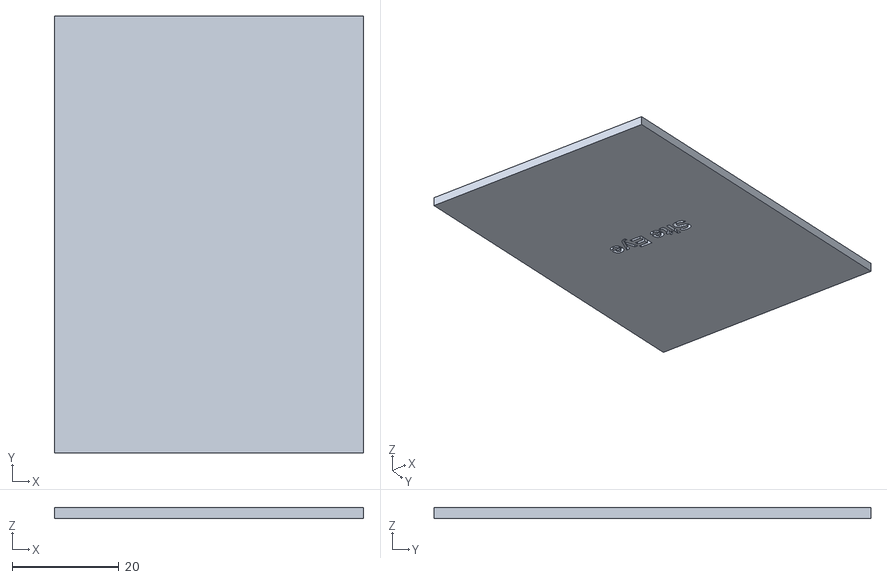
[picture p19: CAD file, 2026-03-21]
case-design/test-text.stl
58.0 x 82.0 x 2.00

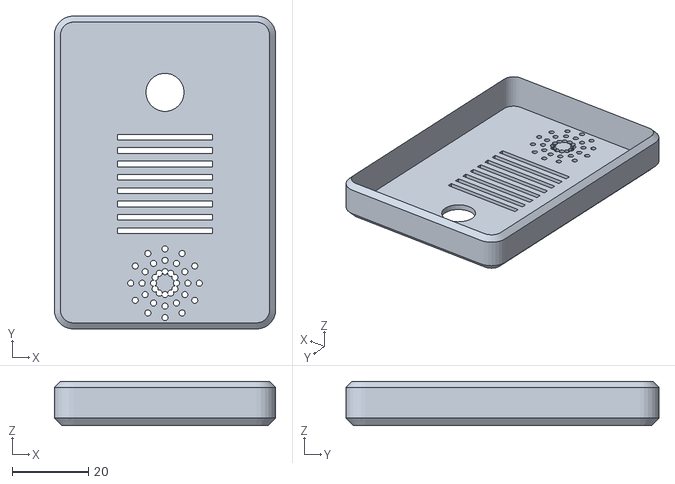
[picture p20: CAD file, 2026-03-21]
case-design/molt-device-back.stl
58.0 x 82.0 x 11.6

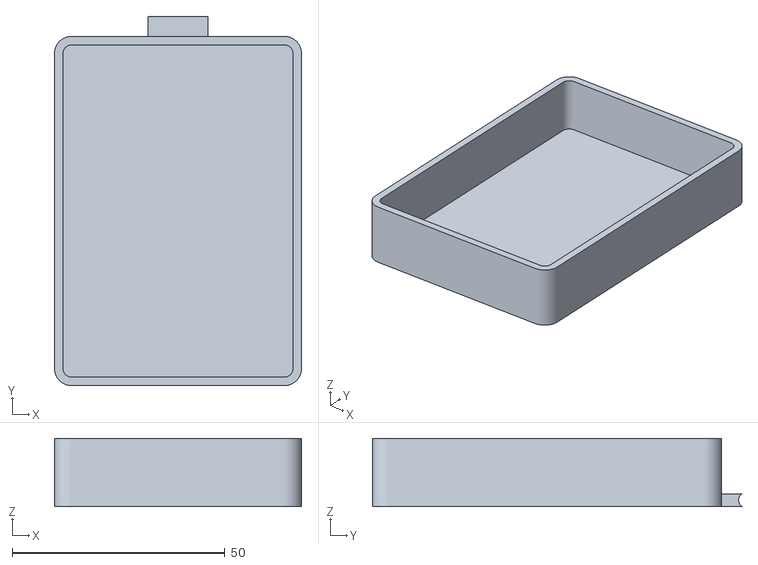
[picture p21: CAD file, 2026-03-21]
case-design/test-notext.stl
58.0 x 86.7 x 16.0

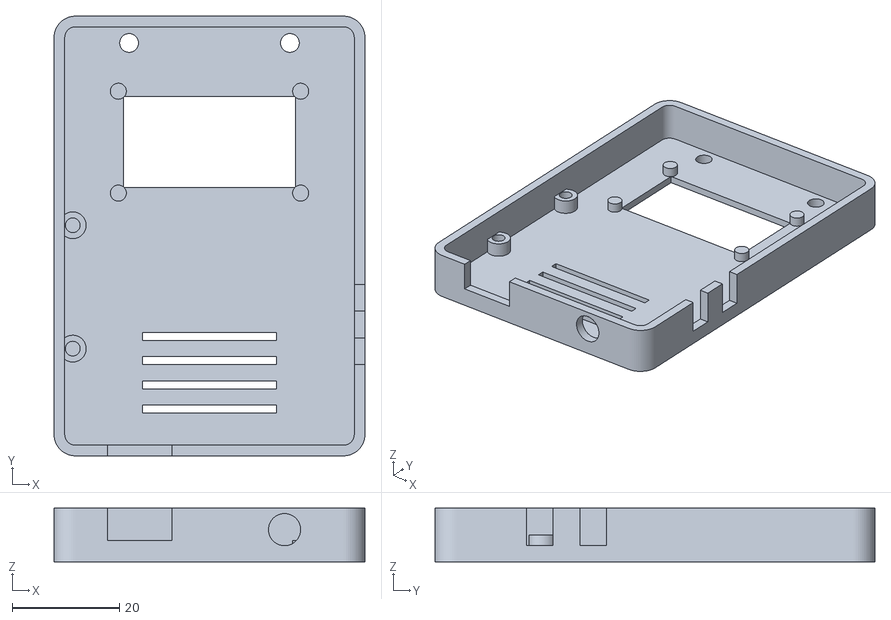
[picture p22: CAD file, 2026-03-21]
case-design/molt-v3-front.stl
58.0 x 82.0 x 10.0

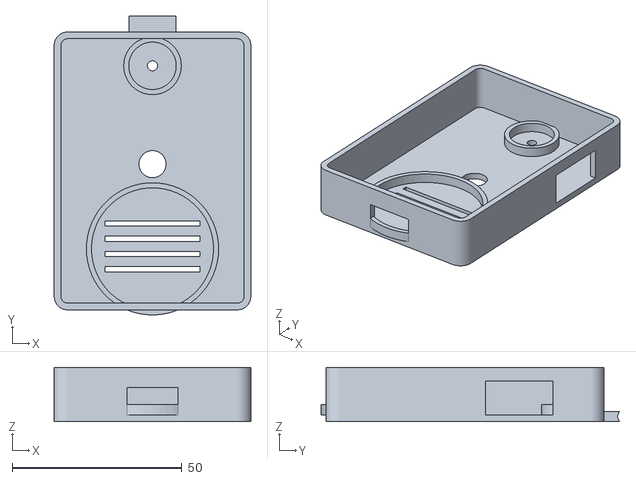
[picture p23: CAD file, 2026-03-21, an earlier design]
case-design/molt-case-front-v5.stl
58.0 x 88.2 x 16.0

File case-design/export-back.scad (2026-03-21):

use <molt-case.scad>
back_shell();

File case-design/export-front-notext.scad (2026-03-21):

use <molt-case.scad>
front_shell();

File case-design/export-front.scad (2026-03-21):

use <molt-case.scad>
front_shell_final();

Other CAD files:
case-design/molt-v3-back.stl
case-design/molt-v2-front.stl
case-design/molt-case-back-v4.stl
case-design/molt-v2-back.stl
case-design/molt-case.scad
case-design/test-notext.scad
case-design/test-text.scad

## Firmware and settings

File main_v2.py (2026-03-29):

#!/usr/bin/env python3
"""SiteEye v2 — Pi Zero 2W + Whisplay HAT + IMX500

Full pipeline:
  - Button tap: voice recording → Whisper STT → Molt → TTS → speaker + LCD
  - Button hold (>1s): camera snap → GPT-4o vision → TTS → speaker + LCD
  - LCD shows premium AI assistant face + response text
  - RGB LED indicates state

Uses WhisPlayBoard's built-in button callbacks (no separate GPIO init).
Display renders at controlled rate to prevent flicker.
"""

import os
import sys
import time
import json
import base64
import signal
import subprocess
import threading
import tempfile
import queue
import requests
from datetime import datetime

sys.path.insert(0, '/home/pi-molt/Whisplay/Driver')

from lcd_ui import LcdUI, STATE_IDLE, STATE_LISTENING, STATE_THINKING, STATE_SPEAKING, STATE_CAMERA, STATE_ERROR, STATE_BOOT

# --- Config ---
PROXY_URL = os.environ.get("SITEEYE_PROXY", "https://molted.tail4a98c5.ts.net")
TELEGRAM_BOT_TOKEN = os.environ.get("TELEGRAM_BOT_TOKEN", "8358560979:AAHEPmk-qQg9RsmrIR2cXyNP4i4u_Hqtl2U")
TELEGRAM_CHAT_ID = os.environ.get("TELEGRAM_CHAT_ID", "8217278203")
CAPTURE_WIDTH = 640
CAPTURE_HEIGHT = 480
MAX_RECORD_SECONDS = 30
BUTTON_HOLD_THRESHOLD = 1.0  # seconds for camera mode
DOUBLE_TAP_WINDOW = 0.4  # seconds — two presses within this = double tap

# Audio device
AUDIO_DEV = "plughw:0,0"
RECORD_FMT = "S16_LE"
RECORD_RATE = "16000"
RECORD_CHANNELS = "1"

# Display target FPS
TARGET_FPS = 6
FRAME_INTERVAL = 1.0 / TARGET_FPS

# Boot animation frame count (matches lcd_ui boot sequence phases)
BOOT_FRAMES = 48  # Must exceed highest frame in _draw_boot phases


def log(msg):
    ts = datetime.now().strftime("%H:%M:%S")
    print(f"[{ts}] {msg}")


class SiteEye:
    def __init__(self):
        self.ui = LcdUI()
        self.board = self.ui.board
        self._running = True
        self._recording = False
        self._record_proc = None
        self._press_time = 0
        self._busy = False

        # Audio feedback files
        self._base_dir = os.path.dirname(os.path.abspath(__file__))
        self._press_time = 0
        self._held_long = False
        self._press_id = 0
        self._tap_count = 0
        self._dispatch_timer = None
        self._live_mode = False       # Gemini Live streaming active
        self._live_session_id = None  # Current live session ID
        self._live_thread = None      # Background streaming thread

        # Register button callbacks
        self.board.button_press_callback = self._on_button_press
        self.board.button_release_callback = self._on_button_release
        log("Button registered via WhisPlayBoard callbacks")

        # Set volume to max
        try:
            subprocess.run(["amixer", "-D", "hw:wm8960soundcard", "sset", "Speaker", "100%"],
                           capture_output=True, timeout=5)
            subprocess.run(["amixer", "-D", "hw:wm8960soundcard", "sset", "Speaker AC Volume", "5"],
                           capture_output=True, timeout=5)
            subprocess.run(["amixer", "-D", "hw:wm8960soundcard", "sset", "Speaker DC Volume", "5"],
                           capture_output=True, timeout=5)
            subprocess.run(["amixer", "-D", "hw:wm8960soundcard", "sset", "Playback", "100%"],
                           capture_output=True, timeout=5)
            subprocess.run(["amixer", "-D", "hw:wm8960soundcard", "sset", "Headphone", "100%"],
                           capture_output=True, timeout=5)
            subprocess.run(["amixer", "-D", "hw:wm8960soundcard", "sset", "Capture", "80%"],
                           capture_output=True, timeout=5)
            log("All volume controls maxed")
        except Exception:
            pass

    def _send_telegram(self, text, image_path=None):
        """Send text/photo to Telegram — mirrors device activity to phone."""
        if not TELEGRAM_BOT_TOKEN:
            return
        try:
            if image_path and os.path.exists(image_path):
                url = f"https://api.telegram.org/bot{TELEGRAM_BOT_TOKEN}/sendPhoto"
                with open(image_path, "rb") as f:
                    requests.post(url,
                        data={"chat_id": TELEGRAM_CHAT_ID, "caption": text[:1024]},
                        files={"photo": f}, timeout=15)
            else:
                url = f"https://api.telegram.org/bot{TELEGRAM_BOT_TOKEN}/sendMessage"
                requests.post(url, json={"chat_id": TELEGRAM_CHAT_ID, "text": text}, timeout=10)
        except Exception as e:
            log(f"Telegram send failed: {e}")

    def _toggle_live_mode(self):
        """Double-tap: toggle Gemini Live streaming conversation on/off."""
        if self._live_mode:
            # Stop live mode
            self._stop_live()
        else:
            # Start live mode
            self._start_live()

    def _start_live(self):
        """Start Gemini Live streaming session."""
        self._play_feedback("click.wav")
        log("🔴 Starting Gemini Live mode")
        self.ui.set_status("LIVE - Connecting...")
        self.ui.set_state(STATE_LISTENING)

        try:
            r = requests.post(f"{PROXY_URL}/live/start", timeout=10)
            if r.status_code == 200:
                data = r.json()
                self._live_session_id = data.get("session_id")
                self._live_mode = True
                log(f"🔴 Live session: {self._live_session_id}")
                self.ui.set_status("LIVE - Speak naturally")

                # Start background audio streaming
                self._live_thread = threading.Thread(target=self._live_audio_loop, daemon=True)
                self._live_thread.start()
            else:
                log(f"Live start failed: {r.status_code}")
                self.ui.set_status("Live failed")
                self._play_feedback("error.wav")
                time.sleep(2)
                self.ui.set_status("")
                self.ui.set_state(STATE_IDLE)
        except Exception as e:
            log(f"Live start error: {e}")
            self.ui.set_status("Live failed")
            self._play_feedback("error.wav")
            time.sleep(2)
            self.ui.set_status("")
            self.ui.set_state(STATE_IDLE)

    def _stop_live(self):
        """Stop Gemini Live session."""
        log("⬛ Stopping Gemini Live mode")
        self._live_mode = False

        if self._live_session_id:
            try:
                requests.post(f"{PROXY_URL}/live/stop",
                    json={"session_id": self._live_session_id}, timeout=5)
            except Exception:
                pass
            self._live_session_id = None

        # Kill any running arecord
        try:
            subprocess.run(["killall", "arecord"], capture_output=True, timeout=2)
        except Exception:
            pass

        self._play_feedback("click.wav")
        self.ui.set_status("")
        self.ui.response_text = ""
        self.ui.set_state(STATE_IDLE)
        self._busy = False
        log("⬛ Live mode ended")

    def _live_audio_loop(self):
        """Continuous streaming: record → send → receive → play concurrently.
        
        Uses persistent arecord/aplay processes instead of per-chunk subprocess calls.
        Two threads: send_loop reads mic and POSTs to proxy, play_loop writes response audio.
        """
        self._busy = True
        play_queue = queue.Queue(maxsize=50)
        error_count = [0]

        # Start continuous arecord (streams raw PCM to stdout, no duration limit)
        try:
            record_proc = subprocess.Popen(
                ["arecord", "-D", AUDIO_DEV, "-f", "S16_LE", "-r", "16000",
                 "-c", "1", "-t", "raw"],
                stdout=subprocess.PIPE, stderr=subprocess.DEVNULL
            )
        except Exception as e:
            log(f"Failed to start arecord: {e}")
            self._busy = False
            return

        def send_loop():
            """Read 8000-byte chunks from mic, POST to proxy, queue response audio."""
            while self._live_mode and self._live_session_id:
                try:
                    # 8000 bytes = 4000 samples = 0.25s at 16kHz 16-bit mono
                    chunk = record_proc.stdout.read(8000)
                    if not chunk:
                        log("arecord stream ended")
                        break

                    r = requests.post(
                        f"{PROXY_URL}/live/audio?session_id={self._live_session_id}",
                        data=chunk,
                        headers={"Content-Type": "application/octet-stream"},
                        timeout=3
                    )

                    if r.status_code == 200 and len(r.content) > 100:
                        # Got response audio — queue for playback
                        try:
                            play_queue.put_nowait(r.content)
                        except queue.Full:
                            pass  # drop oldest if queue full
                        self.ui.set_state(STATE_SPEAKING)
                        self.ui.set_status("LIVE - Speaking")
                        error_count[0] = 0
                    elif r.status_code == 204:
                        self.ui.set_state(STATE_LISTENING)
                        self.ui.set_status("LIVE - Listening")
                        error_count[0] = 0
                    elif r.status_code == 404 or r.status_code == 410:
                        log(f"Session gone ({r.status_code}), stopping live")
                        self._live_mode = False
                        break
                    else:
                        error_count[0] += 1

                except requests.exceptions.Timeout:
                    error_count[0] += 1
                except Exception as e:
                    log(f"Send loop error: {e}")
                    error_count[0] += 1
                    if error_count[0] > 10:
                        log("Too many errors, stopping live mode")
                        self._live_mode = False
                        break
                    time.sleep(0.1)

        def play_loop():
            """Play response audio through continuous aplay process."""
            play_proc = None
            try:
                play_proc = subprocess.Popen(
                    ["aplay", "-D", AUDIO_DEV, "-f", "S16_LE", "-r", "24000",
                     "-c", "1", "-t", "raw"],
                    stdin=subprocess.PIPE, stderr=subprocess.DEVNULL
                )
            except Exception as e:
                log(f"Failed to start aplay: {e}")
                return

            while self._live_mode:
                try:
                    audio = play_queue.get(timeout=1)
                    if play_proc.poll() is not None:
                        # aplay died, restart it
                        try:
                            play_proc = subprocess.Popen(
                                ["aplay", "-D", AUDIO_DEV, "-f", "S16_LE", "-r", "24000",
                                 "-c", "1", "-t", "raw"],
                                stdin=subprocess.PIPE, stderr=subprocess.DEVNULL
                            )
                        except Exception:
                            break
                    play_proc.stdin.write(audio)
                    play_proc.stdin.flush()
                except queue.Empty:
                    continue
                except (BrokenPipeError, OSError):
                    log("aplay pipe broken, restarting")
                    try:
                        play_proc = subprocess.Popen(
                            ["aplay", "-D", AUDIO_DEV, "-f", "S16_LE", "-r", "24000",
                             "-c", "1", "-t", "raw"],
                            stdin=subprocess.PIPE, stderr=subprocess.DEVNULL
                        )
                    except Exception:
                        break

            if play_proc and play_proc.poll() is None:
                try:
                    play_proc.stdin.close()
                    play_proc.terminate()
                    play_proc.wait(timeout=2)
                except Exception:
                    try:
                        play_proc.kill()
                    except Exception:
                        pass

        def text_poll_loop():
            """Periodically check for text from Gemini and update display."""
            while self._live_mode and self._live_session_id:
                try:
                    r = requests.get(
                        f"{PROXY_URL}/live/status?session_id={self._live_session_id}",
                        timeout=2)
                    if r.status_code == 200:
                        data = r.json()
                        text = data.get("text", "")
                        if text:
                            self.ui.response_text = text
                            threading.Thread(target=self._send_telegram,
                                args=(f"🔴 LIVE\n{text}",), daemon=True).start()
                except Exception:
                    pass
                time.sleep(1.5)

        # Launch all threads
        send_thread = threading.Thread(target=send_loop, daemon=True)
        play_thread = threading.Thread(target=play_loop, daemon=True)
        text_thread = threading.Thread(target=text_poll_loop, daemon=True)
        send_thread.start()
        play_thread.start()
        text_thread.start()

        log("🔴 Live streaming threads started")

        # Wait until live mode ends
        while self._live_mode:
            time.sleep(0.2)

        # Cleanup
        try:
            record_proc.terminate()
            record_proc.wait(timeout=2)
        except Exception:
            try:
                record_proc.kill()
            except Exception:
                pass

        # Wait for threads to finish
        send_thread.join(timeout=3)
        play_thread.join(timeout=3)

        self._busy = False
        log("⬛ Live streaming threads stopped")

    def _pcm_to_wav(self, pcm_data, wav_path, sample_rate=24000):
        """Convert raw PCM bytes to a WAV file for aplay."""
        import struct
        with open(wav_path, "wb") as f:
            data_size = len(pcm_data)
            # WAV header
            f.write(b'RIFF')
            f.write(struct.pack('<I', 36 + data_size))
            f.write(b'WAVEfmt ')
            f.write(struct.pack('<IHHIIHH', 16, 1, 1, sample_rate, sample_rate * 2, 2, 16))
            f.write(b'data')
            f.write(struct.pack('<I', data_size))
            f.write(pcm_data)

    def _play_feedback(self, name):
        """Play a short audio feedback file (non-blocking)."""
        path = os.path.join(self._base_dir, "assets", name)
        if os.path.exists(path):
            threading.Thread(target=lambda: subprocess.run(
                ["aplay", "-D", AUDIO_DEV, path],
                capture_output=True, timeout=5
            ), daemon=True).start()

    def _on_button_press(self):
        """Button pressed."""
        self._press_time = time.time()
        self._held_long = False
        self._press_id += 1
        current_id = self._press_id

        # During recording, any press = stop
        if self._recording:
            self._play_feedback("click.wav")
            self._stop_recording()
            return

        # During live mode, any press = stop live
        if self._live_mode:
            self._stop_live()
            return

        if self._busy:
            return

        self._play_feedback("click.wav")

        # Cancel any pending single-tap dispatch
        if self._dispatch_timer and self._dispatch_timer.is_alive():
            self._dispatch_timer.cancel()
            self._dispatch_timer = None

        # Hold detection — runs in background
        def _check_hold():
            time.sleep(BUTTON_HOLD_THRESHOLD)
            if current_id == self._press_id and not self._busy:
                self._held_long = True
                self._play_feedback("camera_beep.wav")
                self.ui.set_status("Release to capture")

        threading.Thread(target=_check_hold, daemon=True).start()

    def _on_button_release(self):
        """Button released — route to voice, camera, or info."""
        if self._busy or self._recording:
            return

        duration = time.time() - self._press_time
        if duration < 0.05:
            return

        # Long press = camera
        if self._held_long or duration > BUTTON_HOLD_THRESHOLD:
            self._tap_count = 0
            threading.Thread(target=self._camera_flow, daemon=True).start()
            return

        # Short tap — count it
        self._tap_count += 1

        if self._tap_count == 1:
            # First tap — wait to see if second comes
            def _dispatch():
                if self._tap_count == 1 and not self._busy:
                    self._tap_count = 0
                    self._voice_flow()
                self._tap_count = 0

            self._dispatch_timer = threading.Timer(DOUBLE_TAP_WINDOW, _dispatch)
            self._dispatch_timer.daemon = True
            self._dispatch_timer.start()

        elif self._tap_count >= 2:
            # Double tap — cancel pending voice dispatch
            self._tap_count = 0
            if self._dispatch_timer:
                self._dispatch_timer.cancel()
                self._dispatch_timer = None
            threading.Thread(target=self._toggle_live_mode, daemon=True).start()

    def _voice_flow(self):
        """Full voice pipeline: record → proxy → TTS → speaker."""
        if self._busy:
            return
        self._busy = True

        log("\U0001f399 Voice flow started")
        self.ui.set_status("Listening")
        self.ui.set_state(STATE_LISTENING)

        audio_path = "/tmp/siteeye_voice.wav"
        try:
            proc = subprocess.Popen(
                ["arecord", "-D", AUDIO_DEV, "-f", RECORD_FMT, "-r", RECORD_RATE,
                 "-c", RECORD_CHANNELS, "-d", str(MAX_RECORD_SECONDS), audio_path],
                stdout=subprocess.DEVNULL, stderr=subprocess.DEVNULL
            )
            self._record_proc = proc
            self._recording = True
            log("Recording... (press button to stop)")

            start = time.time()
            while self._recording and (time.time() - start) < MAX_RECORD_SECONDS:
                elapsed = int(time.time() - start)
                self.ui.set_status(f"Recording {elapsed}s — press to stop")
                time.sleep(0.1)
                if proc.poll() is not None:
                    break

            self._stop_recording()
        except Exception as e:
            log(f"Record error: {e}")
            self.ui.set_state(STATE_ERROR, "Record failed")
            self._play_feedback("error.wav")
            time.sleep(2)
            self.ui.set_status(""); self.ui.set_state(STATE_IDLE)
            self._busy = False
            return

        if not os.path.exists(audio_path) or os.path.getsize(audio_path) < 1000:
            log("Recording too short")
            self.ui.set_status(""); self.ui.set_state(STATE_IDLE)
            self._busy = False
            return

        # Capture background image for context
        img_path = self._capture_photo()

        self.ui.set_status("Processing")
        self.ui.set_state(STATE_THINKING)
        log("\U0001f504 Sending to proxy...")

        try:
            files = {"audio": ("voice.wav", open(audio_path, "rb"), "audio/wav")}
            if img_path:
                files["image"] = ("snap.jpg", open(img_path, "rb"), "image/jpeg")

            r = requests.post(f"{PROXY_URL}/voice_all", files=files, timeout=60)

            for f in files.values():
                try:
                    f[1].close()
                except Exception:
                    pass

            if r.status_code == 200:
                data = r.json()
                transcription = data.get("transcription", "")
                response = data.get("response", "")
                audio_b64 = data.get("audio")

                log(f"\U0001f4dd You: {transcription}")
                log(f"\U0001f916 Molt: {response}")

                # Mirror to Telegram
                threading.Thread(target=self._send_telegram,
                    args=(f"🎙 You: {transcription}\n\n🤖 {response}",), daemon=True).start()

                self.ui.set_status("Speaking")
                self.ui.set_state(STATE_SPEAKING, response)

                if audio_b64:
                    self._play_audio_b64(audio_b64)
                else:
                    time.sleep(2)

                # Keep text visible briefly, then clear
                time.sleep(3)
                self.ui.response_text = ""
            else:
                log(f"\u274c Proxy error: {r.status_code}")
                self.ui.set_status("Error")
                self.ui.set_state(STATE_ERROR, f"Error {r.status_code}")
                time.sleep(2)
        except Exception as e:
            log(f"\u274c {e}")
            self.ui.set_state(STATE_ERROR, str(e)[:40])
            time.sleep(2)

        for p in [audio_path, img_path]:
            try:
                if p:
                    os.remove(p)
            except Exception:
                pass

        self.ui.set_status(""); self.ui.set_state(STATE_IDLE)
        self._busy = False

    def _camera_flow(self):
        """Camera pipeline: capture → show still → vision → TTS."""
        if self._busy:
            return
        self._busy = True

        log("\U0001f4f7 Camera flow started")
        self.ui.set_status("Capturing...")
        self.ui.set_state(STATE_CAMERA)
        self._play_feedback("click.wav")
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

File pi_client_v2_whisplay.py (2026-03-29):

#!/usr/bin/env python3
"""SiteEye v2 — Whisplay HAT client for Pi Zero 2W + IMX500

Whisplay HAT provides:
  - WM8960 audio codec (dual MEMS mics + speaker)
  - 1.69" IPS LCD (240×280, ST7789P3)
  - RGB LED
  - Programmable button (GPIO 17)

Commands via button:
  Short press (<1s) = voice: record → STT → Molt → TTS → speaker
  Long press (>1s)  = camera: snap → GPT-4o vision → TTS → speaker
  Double tap        = device info on LCD

Keyboard fallback:
  v = voice, c = camera, i = info, q = quit
"""

import os
import sys
import time
import json
import subprocess
import threading
import signal
import struct
from datetime import datetime

import requests

# Add Whisplay driver to path
WHISPLAY_DIR = os.path.expanduser("~/Whisplay/Driver")
if os.path.isdir(WHISPLAY_DIR):
    sys.path.insert(0, WHISPLAY_DIR)

# --- Config ---
PROXY_URL = os.environ.get("SITEEYE_PROXY", "https://molted.tail4a98c5.ts.net")
CAPTURE_WIDTH = 640
CAPTURE_HEIGHT = 480
MAX_RECORD_SECONDS = 15
SAMPLE_RATE = 16000
CHANNELS = 1
AUDIO_FORMAT = "S16_LE"

# --- State ---
class State:
    IDLE = "idle"
    LISTENING = "listening"
    PROCESSING = "processing"
    SPEAKING = "speaking"
    CAMERA = "camera"
    ERROR = "error"

current_state = State.IDLE
recording_process = None
press_time = 0.0
whisplay_board = None


def log(msg):
    ts = datetime.now().strftime("%H:%M:%S")
    print(f"[{ts}] {msg}")


# ========================
# LCD Display (Whisplay)
# ========================

def init_display():
    """Initialize the Whisplay LCD."""
    global whisplay_board
    try:
        from WhisPlay import WhisPlayBoard
        whisplay_board = WhisPlayBoard()
        whisplay_board.set_backlight(50)
        log("✅ LCD initialized")
        return True
    except Exception as e:
        log(f"⚠️  LCD init failed: {e}")
        return False


def set_rgb(r, g, b):
    """Set RGB LED color."""
    if whisplay_board:
        try:
            whisplay_board.set_rgb(r, g, b)
        except:
            pass


def draw_text_screen(title, body="", color=(255, 255, 255)):
    """Draw simple text screen on LCD."""
    if not whisplay_board:
        return
    try:
        from PIL import Image, ImageDraw, ImageFont
        img = Image.new('RGB', (240, 280), (10, 10, 26))
        draw = ImageDraw.Draw(img)
        
        # Try to load a decent font, fall back to default
        try:
            font_title = ImageFont.truetype("/usr/share/fonts/truetype/dejavu/DejaVuSans-Bold.ttf", 20)
            font_body = ImageFont.truetype("/usr/share/fonts/truetype/dejavu/DejaVuSans.ttf", 14)
        except:
            font_title = ImageFont.load_default()
            font_body = ImageFont.load_default()
        
        # Title
        draw.text((10, 10), title, fill=color, font=font_title)
        
        # Body — word wrap
        if body:
            y = 45
            words = body.split()
            line = ""
            for word in words:
                test = f"{line} {word}".strip()
                bbox = draw.textbbox((0, 0), test, font=font_body)
                if bbox[2] > 220:
                    draw.text((10, y), line, fill=(200, 200, 220), font=font_body)
                    y += 20
                    line = word
                    if y > 260:
                        break
                else:
                    line = test
            if line and y <= 260:
                draw.text((10, y), line, fill=(200, 200, 220), font=font_body)
        
        # Convert to RGB565 and send
        send_image_to_lcd(img)
    except Exception as e:
        log(f"LCD draw error: {e}")


def draw_eyes(state=State.IDLE):
    """Draw Cozmo-style eyes on LCD."""
    if not whisplay_board:
        return
    try:
        from PIL import Image, ImageDraw
        img = Image.new('RGB', (240, 280), (10, 10, 26))
        draw = ImageDraw.Draw(img)
        
        # Eye parameters based on state
        eye_y = 110
        left_x, right_x = 72, 168
        eye_w, eye_h = 36, 32
        pupil_r = 10
        
        # State-specific modifications
        if state == State.IDLE:
            eye_color = (255, 255, 255)
            pupil_color = (26, 26, 46)
            highlight_color = (136, 204, 255)
        elif state == State.LISTENING:
            eye_color = (255, 255, 255)
            pupil_color = (0, 40, 100)
            highlight_color = (0, 100, 255)
            eye_h = 38  # wider eyes
        elif state == State.PROCESSING:
            eye_color = (255, 255, 255)
            pupil_color = (50, 40, 0)
            highlight_color = (255, 200, 0)
            eye_h = 24  # squinting
        elif state == State.SPEAKING:
            eye_color = (255, 255, 255)
            pupil_color = (40, 0, 60)
            highlight_color = (180, 0, 255)
        elif state == State.CAMERA:
            eye_color = (255, 255, 255)
            pupil_color = (26, 26, 46)
            highlight_color = (255, 255, 255)
        else:  # error
            eye_color = (255, 200, 200)
            pupil_color = (100, 0, 0)
            highlight_color = (255, 50, 50)
        
        # Draw eyes (rounded rectangles)
        for cx in [left_x, right_x]:
            # Eye white
            draw.rounded_rectangle(
                [cx - eye_w, eye_y - eye_h, cx + eye_w, eye_y + eye_h],
                radius=12, fill=eye_color
            )
            # Pupil
            draw.ellipse(
                [cx - pupil_r, eye_y - pupil_r, cx + pupil_r, eye_y + pupil_r],
                fill=pupil_color
            )
            # Highlight
            draw.ellipse(
                [cx - pupil_r + 4, eye_y - pupil_r - 2,
                 cx - pupil_r + 10, eye_y - pupil_r + 4],
                fill=highlight_color
            )
        
        # Status text at bottom
        try:
            font = ImageFont.truetype("/usr/share/fonts/truetype/dejavu/DejaVuSans.ttf", 12)
        except:
            from PIL import ImageFont
            font = ImageFont.load_default()
        
        status_text = {
            State.IDLE: "● Ready",
            State.LISTENING: "● Listening...",
            State.PROCESSING: "● Thinking...",
            State.SPEAKING: "● Speaking...",
            State.CAMERA: "● 📸 Capturing...",
            State.ERROR: "● Error",
        }.get(state, "")
        
        from PIL import ImageFont as IF
        try:
            sfont = IF.truetype("/usr/share/fonts/truetype/dejavu/DejaVuSans.ttf", 12)
        except:
            sfont = IF.load_default()
        draw.text((10, 258), status_text, fill=highlight_color, font=sfont)
        
        send_image_to_lcd(img)
    except Exception as e:
        log(f"Eyes draw error: {e}")
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

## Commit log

2026-03-09 Molt Device v7: eyes, voice, camera, buttons
2026-03-09 rebrand: Molt Device → SiteEye v0.1-beta
2026-03-09 hardware: KiCad project + PCB design docs (BLE mesh-ready)
    [siteeye.kicad_sch]
2026-03-10 main.py: swap Eyes class to use OledUI wrapper, preserve all helper functions
    [main.py]
2026-03-10 latency: gpt-4o-mini, max_tokens 75, tighter prompts, piped TTS playback
    [main.py, server.py]
2026-03-10 voice flow: remove auto-photo capture, voice is voice-only, camera button is separate
2026-03-10 feat: conversation memory + button debounce fixes
    Proxy (server.py):
    - Add conversation history (20 msg buffer, 5 min timeout)
    - Extract DEVICE_MODEL variable for easy model swaps
    - Currently set to Sonnet 4.6
    Client (main.py):
    - Bump button bounce_time 0.2s → 0.5s
    - Add _busy guard to on_voice to prevent double-fire
    [main.py, server.py]
2026-03-21 Add v6 case design — 3D printed wearable enclosure
    - Add case-design/ directory with OpenSCAD source and STL exports (v3-v6)
    - Add case-design/README.md: full design documentation
    - Badge-sized (58×82×34mm) lanyard-worn form factor
    - Two-piece snap-fit: front (camera) + back (OLED)
    - Component mounting: Pi Zero 2W, IMX500, OLED, speaker, mic, PiSugar
    - v6 13-point redesign: corrected mounts, speaker/mic cradles, USB access
    - Printing instructions (PETG, settings) and step-by-step assembly guide
    - Add build-photos/ directory with 8 physical prototype photos
    - Update README.md:
    - Add Case Design section with enclosure overview and build photo table
    - Add Hardware Status table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
    [export-back.scad, export-front-notext.scad, export-front.scad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]
2026-03-28 Add v1-lite camera client + camera test script
    - pi_client_v1_lite.py: full camera+vision+detection client
    - pi_camera_test.py: minimal camera→proxy test
    - Proxy URL updated to Tailscale Funnel (HTTPS)
    - Removed hardcoded bot token (use env var)
2026-03-28 Add v2 Whisplay client — LCD eyes, mic, speaker, button
    - pi_client_v2_whisplay.py: full v2 client with Whisplay HAT integration
    - LCD: Cozmo-style color eyes (240x280), status bar, word-wrapped text
    - Audio: WM8960 record (16kHz S16_LE) + playback via codec
    - Button: tap=voice, long press=camera (GPIO 17)
    - RGB LED: state-based colors (idle/listening/thinking/speaking/error)
    - Keyboard fallback when button not available
    - Camera: IMX500 unchanged from v1
    [pi_client_v2_whisplay.py]
2026-03-28 Add v2 Whisplay HAT client
    - LCD eyes (Cozmo-style, color, 240x280)
    - WM8960 mic recording (16kHz S16_LE mono)
    - WM8960 speaker playback
    - RGB LED state indicators
    - Voice flow: record → STT → Molt → TTS → speaker
    - Camera flow: snap → vision → LCD text → TTS
    - Button support (GPIO 17, short=voice, long=camera)
    - Keyboard fallback: v/c/i/q commands
    - PiSugar battery readout via I2C
    [pi_client_v2_whisplay.py]
2026-03-29 Add v2 Whisplay HAT client
    - WM8960 audio (record from dual MEMS mics, play through speaker)
    - Button: short press = voice, long press = camera
    - Keyboard fallback for testing without button
    - Full voice flow: record → proxy STT → Molt → TTS → speaker
    - Full camera flow: snap → proxy vision → LCD display
    - Graceful degradation if hardware not ready
    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
    [pi_client_v2_whisplay.py]
2026-03-29 SiteEye v2: Whisplay HAT support — LCD eyes, voice, camera
    - main_v2.py: full v2 client with button handler, voice pipeline, camera pipeline
    - lcd_ui.py: Cozmo-style animated eyes on 240x280 color LCD (ST7789)
    - Idle: blinking, saccade eye movements
    - Listening: wide eyes, blue pulse, blue LED
    - Thinking: squinted eyes, yellow dots, yellow LED
    - Speaking: relaxed eyes, purple waveform, purple LED
    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
2026-03-29 SiteEye v2.1: Full expressive face — mouth, eyebrows, moods
    LCD UI overhaul:
    - Animated mouth: opens/closes during speech, smiles, frowns, surprised O
    - Tongue hint when wide open, teeth at top, curved smile line when closed
    - Eyebrows: raise (attentive/surprised), furrow (angry/worried), neutral
    - Smooth transitions: all expression values lerp between states
    - Pupil dilation: grows when focused (listening), shrinks for camera flash
    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
2026-03-29 Fix LCD layout: respect 20px chamfers, fill full 240x280 screen
    - Added safe zones: SAFE_TOP=22, SAFE_BOT=258, SAFE_LEFT=12
    - Status text and mode bar moved inside chamfer-safe area
    - Eyes enlarged (W=38, H=32, pupil=11) for bigger screen presence
    - Eye center moved to Y=105, mouth to Y=160 — better vertical spread
    - Boot screen, camera screen, indicators all repositioned
    - Text wrapping respects safe margins on both sides
    - No more content clipping in rounded corners
    [lcd_ui.py]
2026-03-29 SiteEye v2.2: Neural Mesh Face — particles form a network face
    Complete UI rewrite — the face is now a living network mesh:
    Boot animation:
    - Particles scatter randomly then converge into face shape
    - Edges fade in as particles find their positions
    - 'SiteEye v2 initializing' fades in at bottom
    Face structure:
    - Eyes: elliptical particle outlines + inner pupil ring + glowing center
    - Eyebrows: particle arcs above eyes, raise/furrow with state
    - Mouth: particle line that curves (smile/frown) and opens (speaking)
    - 20 ambient particles floating in background with faint connections
    Physics:
    - Spring-based particle movement (smooth, organic)
    - Per-particle drift phase + speed (no two move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
    [lcd_ui.py]
2026-03-29 Fix button + display flicker — industry standard
    Button fix:
    - Removed separate RPi.GPIO setup that conflicted with WhisPlayBoard's BOARD mode
    - Now uses board.button_press_callback / button_release_callback
    - WhisPlayBoard already owns GPIO edge detection — no conflict
    - Added _busy flag to prevent overlapping voice/camera operations
    Display fix:
    - Controlled framerate at 8 FPS (FRAME_INTERVAL = 125ms)
    - Frame timing: render + sleep to exact interval (no busy loop)
    - Boot animation runs 35 frames at controlled rate before going idle
    - Eliminates rapid full-screen SPI transfers that caused visible flicker
    Other:
    - Cleaner shutdown handling
    - Separated boot animation from main display l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
    [main_v2.py]
2026-03-29 v2.3: Revert to Cozmo face + fix flicker + fix recording race
    LCD:
    - Reverted to Cozmo-style eyes/mouth/brows (v2.1) per Michael's feedback
    - Double-buffer: caches last frame bytes, skips SPI if identical
    - Direct SPI via set_window + _send_data (bypasses list() conversion)
    - 6 FPS target (smooth enough for expressions, minimal SPI hammering)
    Recording fix:
    - Race condition: button_release could fire _stop_recording before Popen
    assigned to self._record_proc → NoneType.poll() error
    - Fix: assign proc to local var first, then set self._record_proc,
    then set self._recording flag. Stop checks local proc reference.
    Button:
    - Still using WhisPlayBoard native callbacks (no GPIO conflict)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
    [lcd_ui.py, main_v2.py]
2026-03-29 Fix: aplay timeout 30→120s, clear text 3s after speech ends
    [main_v2.py]
2026-03-29 v2.4: Better text display + camera TTS fix
    Text display:
    - Response text now takes full area below face — mode bar hidden while text shows
    - Dark background behind text for contrast/readability
    - Scroll indicator (...) when text is truncated
    - No more 'Ready' overlapping the response
    Camera TTS:
    - Better error logging for TTS failures
    - Increased TTS request timeout to 60s
    - Shows 'Analyzing image...' during thinking state
    Layout:
    - Text area: y=180 to bottom safe zone, 5 lines max, 18px line height
    - Mode bar only shows when no response text is displayed
    [lcd_ui.py, main_v2.py]
2026-03-29 Add startup sound: 'SiteEye — online and ready to work'
    - Generated via OpenAI TTS (fable voice, 1.05x speed)
    - assets/startup.wav plays after boot animation + health check
    - Plays through WM8960 speaker on boot
2026-03-29 v2.5: Camera TTS fix + image preview on LCD
    - /tts endpoint returns raw WAV bytes, NOT JSON — was trying json.loads on binary
    - New _play_audio_raw() handles raw bytes directly
    - _play_audio_b64() now delegates to _play_audio_raw()
    Image preview:
    - After camera capture, photo displays on LCD while analyzing
    - Scales/crops to fill 240×180 area (letterbox style)
    - 'Analyzing...' text below the image
    - Thin border around photo for polish
    - Photo stays visible until vision response arrives
    This should fix the camera voice feedback completely.
    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
    [lcd_ui.py, main_v2.py]
2026-03-29 v2.6: Photo stays on screen through entire camera flow
    - Photo now persists as overlay state (_photo_img) — display loop renders it
    - No more flash-and-disappear: photo stays from capture through TTS playback
    - Flow: capture → photo on LCD + 'Analyzing...' → response text below photo → voice → hold 4s → clear
    - Photo text area: 6 lines, word-wrapped, dark background below image
    - set_photo_text() updates text without clearing photo
    - clear_photo() returns to face mode
    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
2026-03-29 Fix: detect headless mode — no stdin.isatty() means service, skip keyboard loop
    [main_v2.py]
2026-03-29 v3.0: Pitch-ready UX overhaul — professional AI field assistant
    Complete visual redesign for management demo:
    Palette: Deep navy #080C14, cool white #E8ECF0, teal accent #4A9ECC
    - All toy colors eliminated. Muted LED values. Premium feel.
    Boot sequence (45 frames, 4 phases):
    1. 'SITEEYE' fades in centered (monospace bold)
    2. Thin progress bar fills with accent
    3. 'v2.0 | AI-POWERED FIELD ASSISTANT' subtitle
    4. Sequential system checks: Camera ✓ Audio ✓ Network ✓
    Face — minimal, geometric, professional:
    - Clean rounded rectangle eyes with breathing highlight
    - Single bright dot reflection (no multiple highlights)
    - Subtle gray gradient edges for depth
    - No eyebrows, no tongue, no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
    [lcd_ui.py, main_v2.py]
2026-03-29 v3.1: Bigger boot logo (38px), startup chime, all volume maxed
    - SITEEYE title: 28px → 38px monospace bold — readable from arm's length
    - Subtitle bumped to 11px
    - Boot positions adjusted for larger title
    - Startup chime: 1.2s ascending C-E-G major arpeggio (synthesized)
    - Chime plays before voice announcement
    - Added Playback 100% + Headphone 100% to volume init (was missing)
    - All 5 volume controls now maxed: Speaker, AC, DC, Playback, Headphone
    [lcd_ui.py, main_v2.py]
2026-03-29 v3.2: Full button UX overhaul + audio feedback + idle hints
    Button UX (the big one):
    - PRESS: instant click sound + LCD shows 'Release → Voice | Hold → Camera'
    - HOLD >1s: camera beep + LED white + 'Release to capture photo'
    - RELEASE short: voice recording starts
    - RELEASE long: camera capture starts
    - DURING RECORDING: status shows 'Recording Xs — press to stop'
    - ERROR: error tone plays
    Audio feedback:
    - click.wav: short 1200Hz click on every button press
    - camera_beep.wav: 880Hz tone when hold threshold crossed
    - error.wav: low 330Hz tone on failures
    - All non-blocking (threaded playback)
    Idle hints:
    - Bottom of screen cycles: 'Tap button → Voice' / 'Hold button → Camera'
    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
    [lcd_ui.py, main_v2.py]
2026-03-29 v3.3: Fix button UX + remove blue bubble + clean status flow
    Button fixes:
    - Recording stop moved to _on_button_press (any press during recording = stop)
    - press_id counter cancels stale hold timers (no more ghost camera triggers)
    - 50ms debounce on release (ignore spurious GPIO noise)
    - _on_button_release returns immediately if recording (already handled in press)
    Blue bubble killed:
    - _draw_listening_ring: replaced floating ellipse with clean audio level bars
    - 5 small pulsing bars centered below face, no more random blue circle
    Status text cleanup:
    - Every idle transition clears status text
    - Listening shows 'Listening', thinking shows 'Processing'
    - Button hints only during press→rel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
    [lcd_ui.py, main_v2.py]
2026-03-29 v3.4: Readable UI + live viewfinder + accurate status text
    Readability:
    - font_sm: 11→13px, font_md: 13→14px — visible at arm's length
    - Status bar: dot r=4 (was 3), status text in white (was dim), SiteEye in accent
    - Idle hints use medium font, centered
    - Chime volume reduced ~35%
    Live viewfinder (#4):
    - Hold button → camera starts streaming live to LCD at ~12fps
    - Crosshair overlay + corner brackets + 'Press to capture' hint
    - Press button again to take the still photo
    - Then proceeds with vision analysis + TTS as before
    - 30s safety timeout on viewfinder
    - Temporary button callback swap for shutter trigger
    Accurate status text (#3):
    - Every state transition updates status: Liste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
    [lcd_ui.py, main_v2.py]
2026-03-29 v3.5: Black/Gold theme + Telegram mirror + double-tap info + Roboto Condensed
    Color theme:
    - Pure black background, white text, yellow/gold accent (#FFC828)
    - Gold LED tones across all states
    - Industrial feel — construction-grade, not consumer tech
    Fonts:
    - Roboto Condensed (Regular + Bold) — narrow industrial font
    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
2026-03-29 v3.6: Bigger boot text + fix boot loop + larger system checks
    Boot:
    - SITEEYE title: 48px Roboto Condensed Bold in GOLD — fills the screen
    - Subtitle: 14px 'AI-POWERED FIELD ASSISTANT' in white
    - System checks: 14px with bigger spacing (20px between lines)
    - Progress bar wider (180px) and thicker (4px)
    - 5 phases now: title → bar → subtitle → checks → auto-idle
    - Phase 5 auto-transitions to idle (fixes infinite boot loop)
    - BOOT_FRAMES bumped to 48
    Fix: boot was looping because display thread kept rendering
    STATE_BOOT after main thread's frame loop finished. Now
    _draw_boot auto-sets state to idle on frame 45+.
    [lcd_ui.py, main_v2.py]
2026-03-29 Fix: replace Unicode checkmark with ASCII 'OK' — old Pillow cant render Unicode with Roboto
    [lcd_ui.py]
2026-03-29 Fix: replace all Unicode in LCD text — Roboto on Pi is latin-1 only
    [lcd_ui.py, main_v2.py]
2026-03-29 v3.7: Font size overhaul across entire app
    Fonts (all Roboto Condensed):
    - sm: 14->16px (status bar, hints)
    - md: 15->18px (response text, prompts, viewfinder)
    - lg: 24->28px (headings)
    - mono: 48px (boot SITEEYE — unchanged, already big)
    - sub: 14->16px Bold (boot subtitle)
    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
2026-03-29 Fix: Thread.cancel() error — use tap_count reset instead
    [main_v2.py]
2026-03-29 v3.9: Clean button state machine — tap/hold/double-tap
    Rewrote button handling from scratch:
    - Uses threading.Timer (has .cancel()) not raw Thread
    - Single tap: Timer waits 400ms, if no second tap fires voice
    - Double tap: second tap within 400ms cancels Timer, fires info
    - Long hold: background thread detects, sets _held_long flag
    - Release checks flag for camera
    - Recording stop: clean, on press during recording
    - No more Thread.cancel() errors
    - No more stale timer threads
    - No more race conditions between tap detection and dispatch
    [main_v2.py]
2026-03-29 Move chime to boot animation — plays during progress bar phase
    - Chime now fires at frame 8 (non-blocking, threaded aplay)
    - Syncs with progress bar appearing on screen
    - Voice announcement still plays after boot completes
    - Feels like a proper device powering on
2026-03-29 Fix viewfinder shutter — button press was blocked by _busy flag
    Root cause: during camera flow _busy=True, so _on_button_press
    returned early before reaching the callback swap. Shutter never fired.
    Fix: check _camera_shutter flag BEFORE _busy check in _on_button_press.
    When _camera_shutter is False (viewfinder active), any press sets it True.
    No more callback swapping — cleaner, no race conditions.
    States: None=not in viewfinder, False=waiting for capture, True=captured
    [main_v2.py]
2026-03-29 Remove live viewfinder — back to simple capture flow
    Hold button → capture still → show on LCD → analyze → TTS
    No more picamera2 streaming, no callback swaps, no shutter flags.
    Uses rpicam-still (proven reliable) for capture.
    Live viewfinder was causing hangs and button conflicts.
    [main_v2.py]
2026-03-29 v4.0: Gemini Live mode — double-tap for real-time streaming conversation
    New mode: Gemini Live (double-tap to toggle)
    - Double-tap → starts Gemini Live WebSocket session via proxy
    - Continuous audio streaming: mic → proxy → Gemini → audio back → speaker
    - Status shows 'LIVE - Speak naturally' / 'LIVE - Listening' / 'LIVE - Speaking'
    - Any button press during live mode = stop
    - Function calls route to OpenClaw (check_email, check_calendar, ask_molt)
    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
2026-03-29 v4.2: Fix live session dying after first response + faster audio chunks
    Proxy: wrap receive() in while loop so session survives turn completion
    Pi: audio chunks 1s → 0.5s (8000 samples) for lower latency
    [main_v2.py]
2026-03-29 v4.3: Production Gemini Live — continuous streaming
    - Replaced per-chunk arecord subprocess with continuous arecord pipe
    - Two threads: send_loop (mic→proxy) + play_loop (proxy→speaker)
    - Continuous aplay process for gapless audio playback at 24kHz
    - 8000-byte chunks (0.25s) for low latency
    - Text polling thread for display updates
    - Auto-restart aplay on pipe breaks
    - Error counting with auto-stop after 10 consecutive failures
    [main_v2.py]
